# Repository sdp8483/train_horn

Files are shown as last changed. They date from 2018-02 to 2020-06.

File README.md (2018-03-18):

# Train Horn Synthesis with the MSP430FR2000
This readme is a short version of the blog post avalible on my personal website. Please read the blog post if you need more information: [link to blog]

## Introduction
The hardware and code presented is designed to simulate the sound of a train horn (or come as close as possible with the given hardware). Specifically is is designed to synthesize the sound of a [Leslie S-3L Locomotive Air Horn](http://www.dieselairhorns.com/sounds/LeslieS3L.mp3).

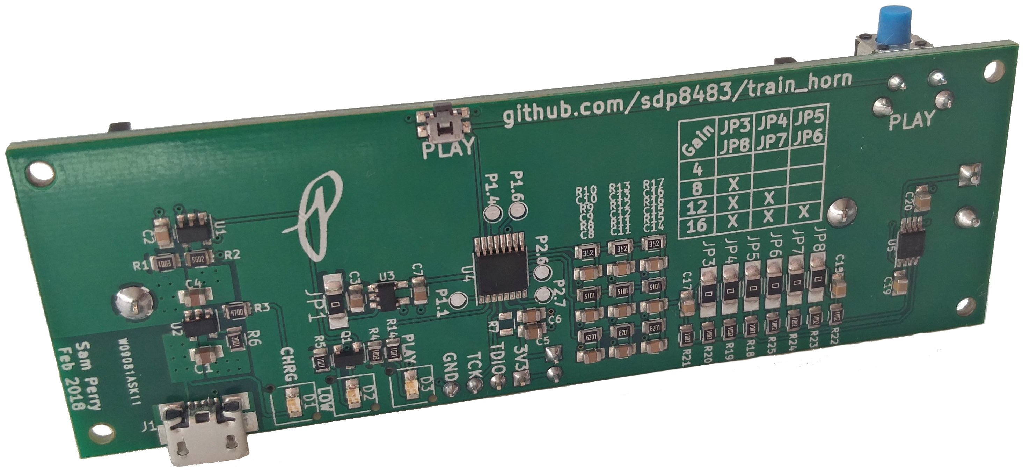
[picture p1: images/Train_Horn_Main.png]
Train Horn Assembly


The final design is battery powered for portability. It uses a 18650 LiPo cell and features an onboard charger using a standard micro USB port and a low battery indicator LED.

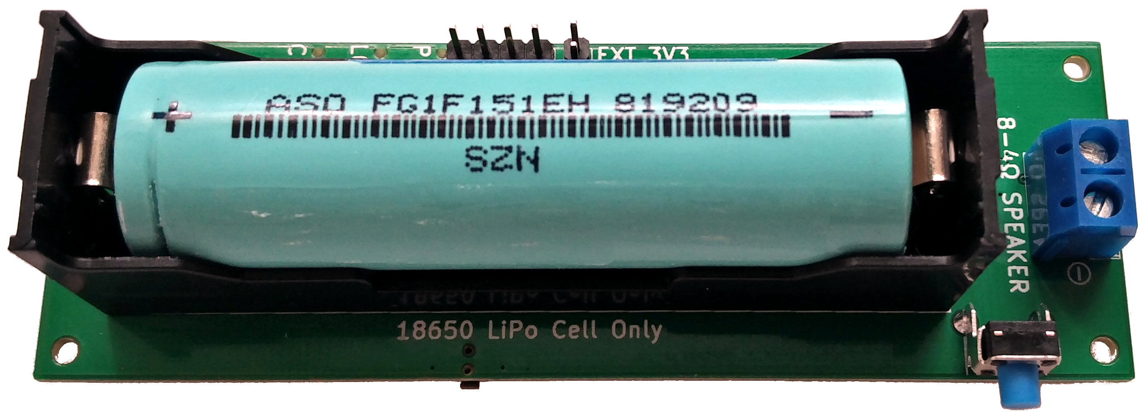
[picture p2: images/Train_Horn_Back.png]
Train Horn Assembly Back


The circuitry is able to drive a standard speaker load of 8-4Ω for mono sound. Four adjustable gain settings of 4, 8, 12, and 16 are available for setting the output volume of the audio amplifier with minimal modifications.

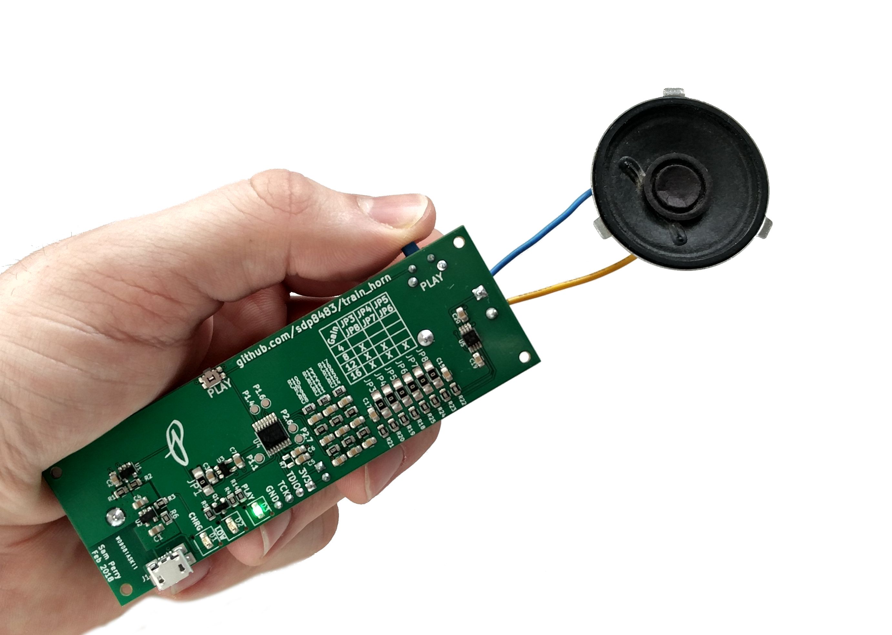
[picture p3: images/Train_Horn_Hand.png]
Train Horn in Hand


An onboard microcontroller generates the chord and enables the user control of the sound though a simple push button. The [MSP430FR2000](http://www.ti.com/product/MSP430FR2000) was chosen due to its low cost in single quantities and availability at the time of designing this product. The MSP430 line was chosen specifically to develop a familiarity with using the product.

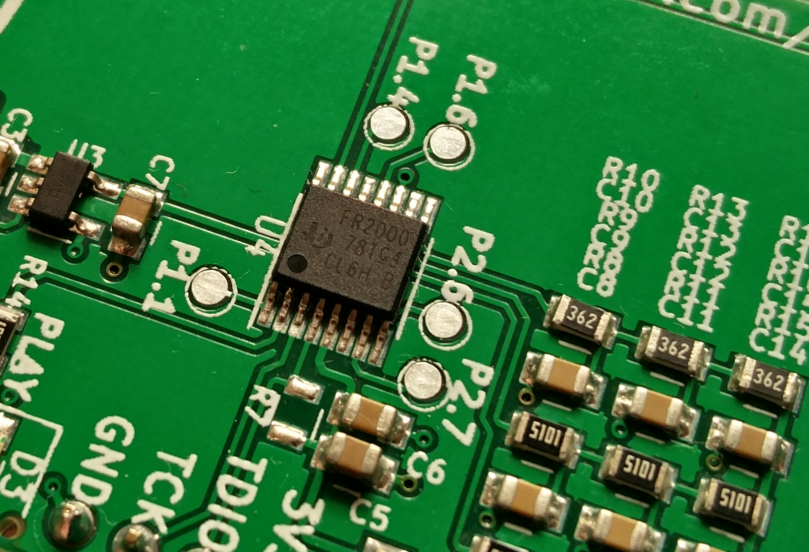
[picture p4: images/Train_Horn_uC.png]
MSP430FR2000 on PCB


## A Brief Overview

PCB Front Annotation
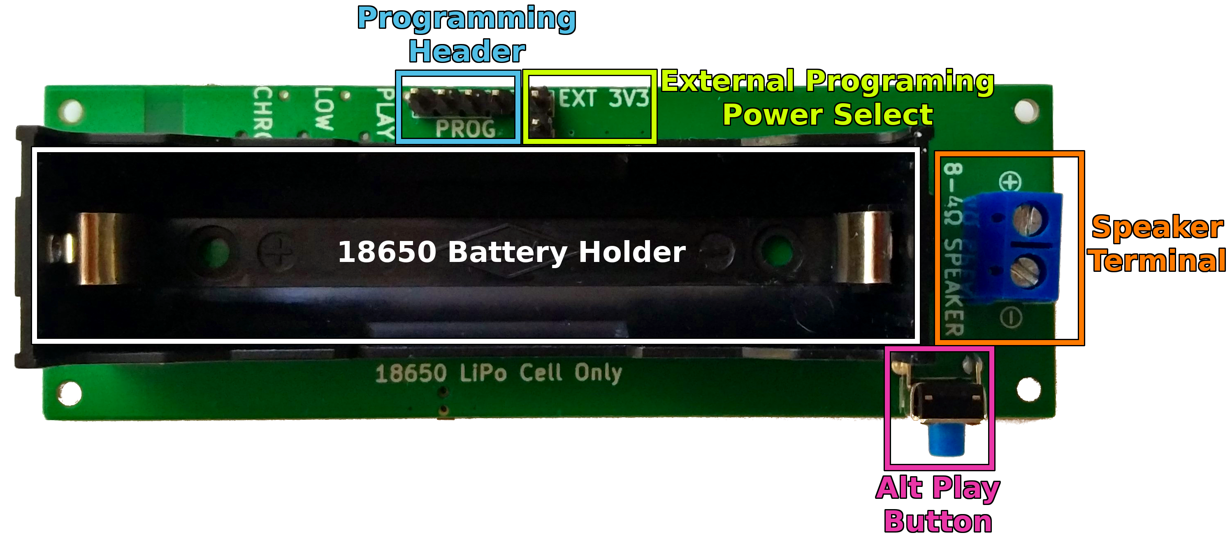
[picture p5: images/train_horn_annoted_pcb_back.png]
PCB Back Annotation


A 4-8Ω speaker is connected to the speaker terminal. The device is powered from a 18650 LiPo cell which is charged using the micro USB port, a blue LED indicates that the battery is charging. The charging circuitry is capable of charging the battery at a maximum current of 500mA.  The low battery detection circuitry will illuminate a red LED indicator light when the battery voltage is low and requires charging. The audio amplifier gain (volume) is configured using jumpers JP3-JP8 and is set to 16 by default. Pressing and holding either the small SMD or the larger right angle play button generates sound. A green LED is illuminated while sound is playing. Releasing the button stops sound generation.

## Schematic

Schematic

## Detailed Description
### Sound Generation
The Leslie S-3L Locomotive Air Horn generates its distinctive [sound](http://www.dieselairhorns.com/sounds/LeslieS3L.mp3) using a three tone chord of approximately C, D#, and A [http://atsf.railfan.net/airhorns/s3l.html](http://atsf.railfan.net/airhorns/s3l.html).

The onboard microcontroller generates the chord using three 50% duty cycle PWM signals. Since the MSP430FR2000 microcontroller has only one general purpose timer the method outlined in TI app note [SLAA513A](http://www.ti.com/lit/an/slaa513a/slaa513a.pdf) was implemented to generate multiple time bases on a single MSP430 timer module. This enables use of the lower cost MSP430FR2000 instead of having to move to a potentially higher cost MSP430 microcontroller with three separate timer modules.

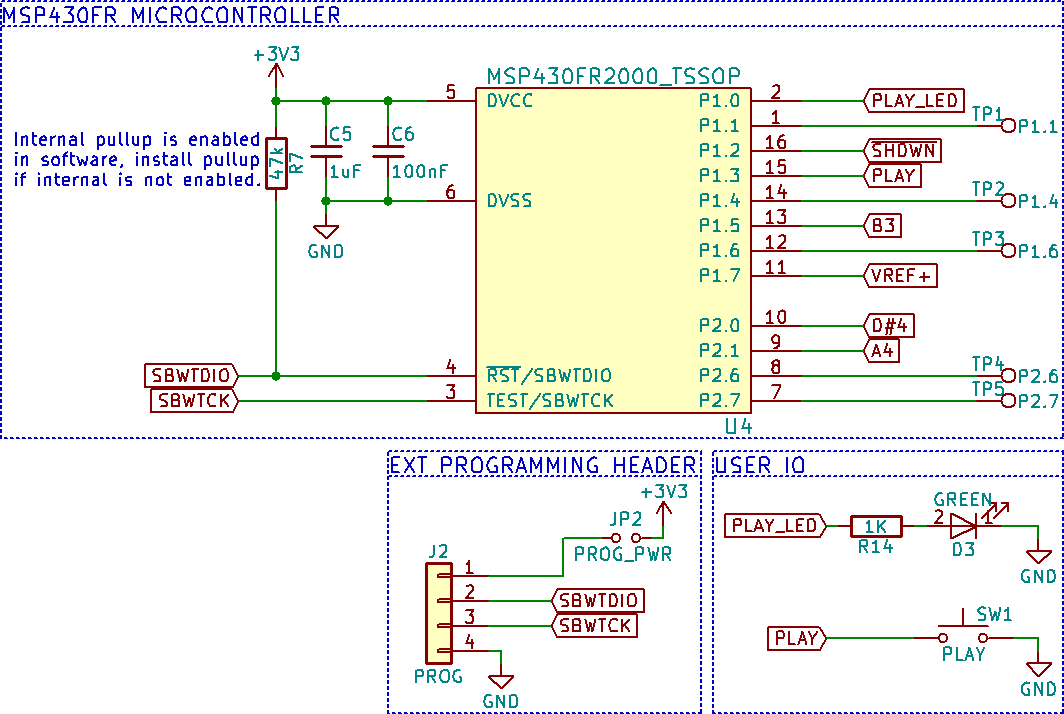
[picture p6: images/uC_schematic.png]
uC Schematic


Each PWM signal from the microcontroller is passed through a three stage RC low pass filter to produce a sine wave on the output.  The RC low pass filter was designed with the help of the following online RC low pass filter calculator: [http://sim.okawa-denshi.jp/en/CRtool.php](http://sim.okawa-denshi.jp/en/CRtool.php)

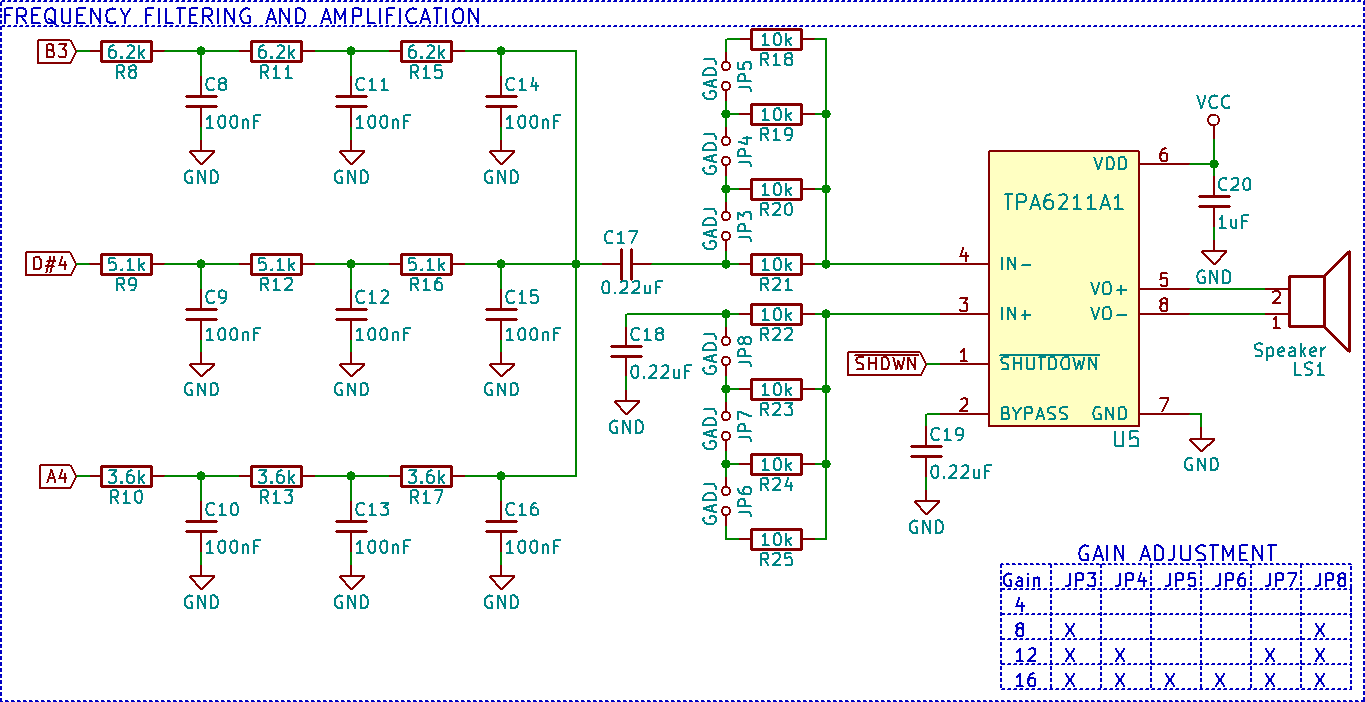
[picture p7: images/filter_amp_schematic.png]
Filter Amp Schematic


After each PWM signal is converted to a sine wave the signals are then mixed together before entering the audio amplifier. The audio amplifier is a [TPA6211A1](http://www.ti.com/lit/ds/symlink/tpa6211a1.pdf) mono audio power amplifier. The audio amplifier has 4 adjustable gain settings that can be changed by desoldering the smd jumpers (JP3 to JP6) as indicated by the table. For example to set a gain of eight JP4, JP5, JP6, and JP7 would be removed from the PCB. The amplifier can drive a 4-8Ω speaker.

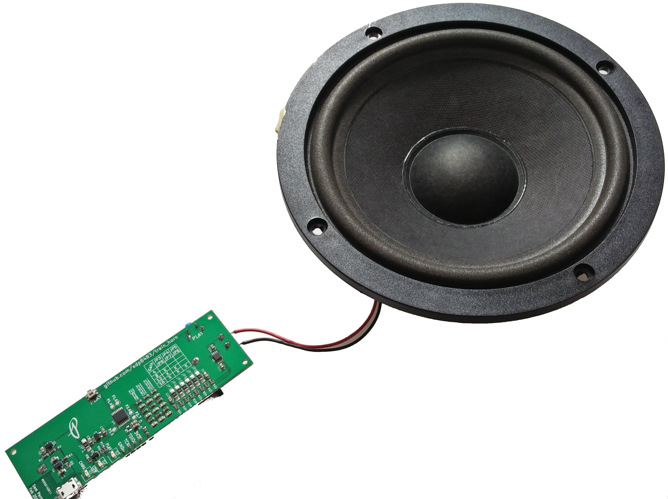
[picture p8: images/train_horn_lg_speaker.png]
Large Speaker


### Battery Circuitry
The circuit is powered with a standard 18650 LiPo cell. Be sure to observe polarity of the battery holder. The positive end of the battery installs opposite of the speaker terminal. Installing the battery in reverse polarity will destroy the battery charger IC and will damage the remaining circuitry. Don't ask me how I know.

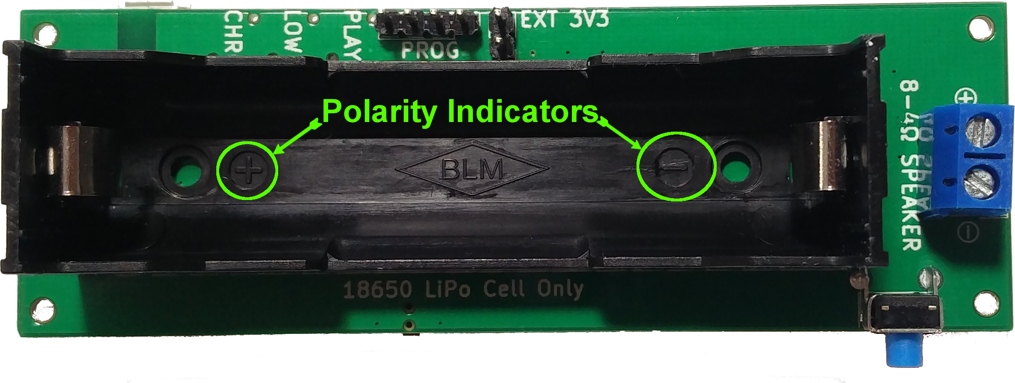
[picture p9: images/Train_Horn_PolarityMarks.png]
Observe Polarity!


Charging is controlled by the [MCP73831](https://www.microchip.com/wwwproducts/en/en024903) charge management IC at a maximum charging current of 500mA using the micro USB port. This USB port if for charging only, the data lines are not connected to the MSP430FR2000 microcontroller. A blue LED indicator is turned on while the battery charges. The LED turns off to indicate that the battery is fully charged.

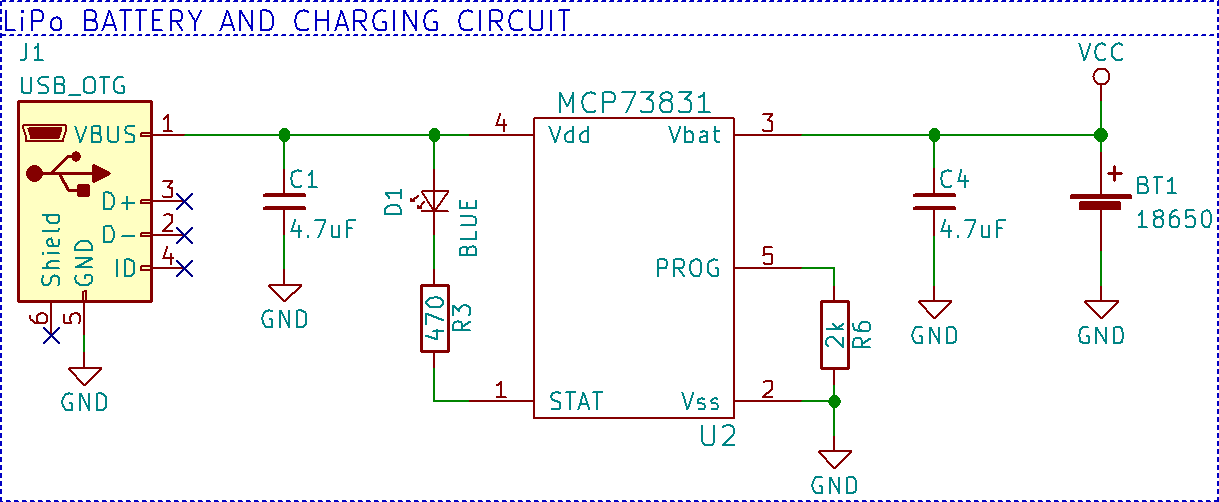
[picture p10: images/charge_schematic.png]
Battery Schematic

Battery Charging

A red LED is used to indicate a low battery voltage. The [MIC7221](http://ww1.microchip.com/downloads/en/DeviceDoc/mic7211.pdf) comparator is used to illuminate the LED when the battery voltage drops below ~3.3V. The internal 1.2V reference from the microcontroller is used as the voltage reference for the comparator.

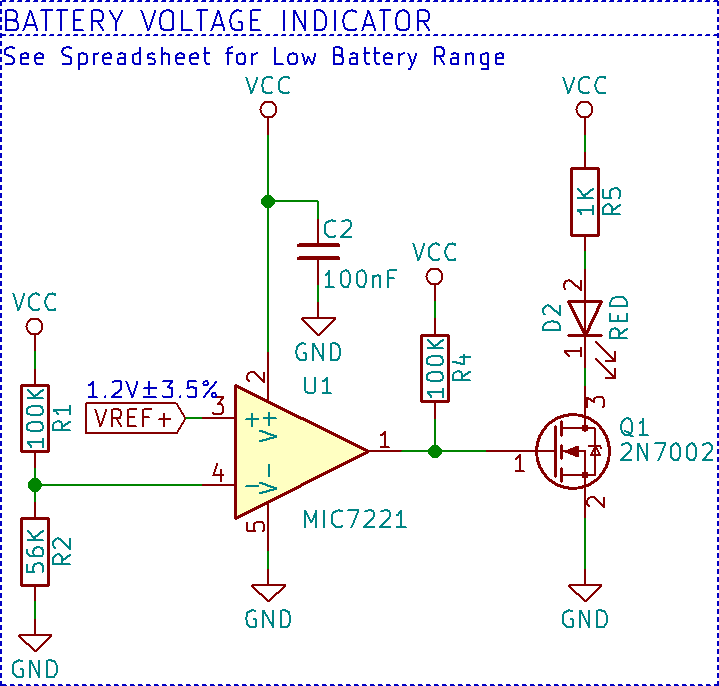
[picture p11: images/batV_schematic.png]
Low Battery Schematic


The onboard comparator of the MSP430FR2000 was not used due to issues with getting it to function correctly, most likely error on my part. To save time and frustration an external comparator was used instead.

Low Battery LED

The MSP430FR2000 microcontroller has a maximum voltage supply rating of 3.6V requiring a 3.3V low dropout regulator to prevent a fully charged LiPo cell voltage of 4.2V damaging the microcontroller. SMD JP1 can be desoldered from the circuit to put the LDO in shutdown mode, turning off the microcontroller.

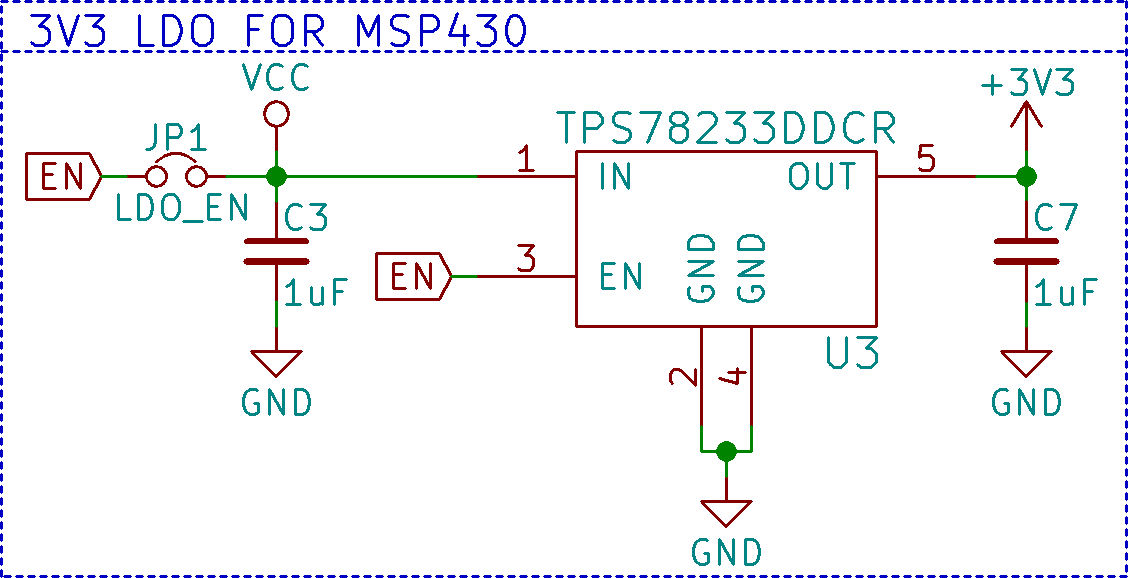
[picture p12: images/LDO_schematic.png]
LDO Schematic


### Firmware
The microcontroller spends much of its time in a low power sleep mode, the full circuit draws about 0.3mA of quiescent current. A 1600mAh LiPo cell will have a standby life of over [3700 hours](https://www.digikey.com/en/resources/conversion-calculators/conversion-calculator-battery-life) or 154 days!

Sound is generated when the user presses and holds down the play button. There are two play buttons on the PCB, a small SMD button and a friendlier medium sized right angle button. The PCB was originally designed to use only the SMD button but a last minute change added the right angle through hole button. Both are populated to allow multiple options of triggering sound generation. The green LED indicator is used to indicate when the sound is being generated.

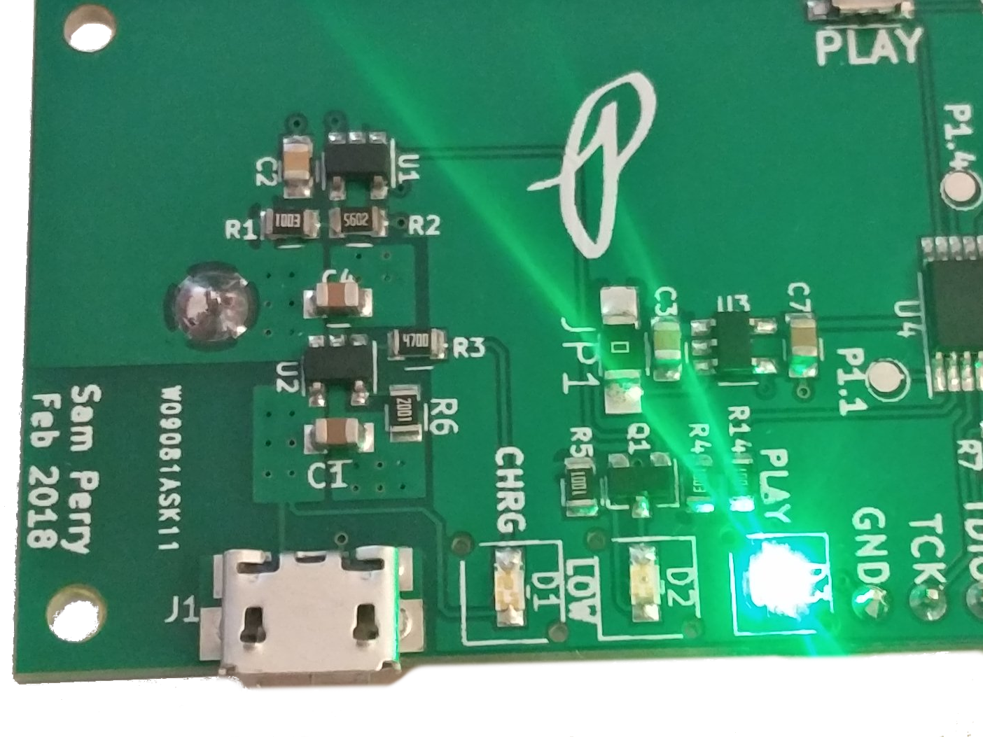
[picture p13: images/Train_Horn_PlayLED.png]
Play LED


Firmware is avalible here: [firmware/train_horn_hold/train_horn_hold.c](firmware/train_horn_hold/train_horn_hold.c)

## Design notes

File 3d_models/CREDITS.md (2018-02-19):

## Footprint Library Credits

The credits of 3D models are listed in respective folder.  
Please fill all 3D models credits and info source data accordingly.  

### Info requirements:
- Author
- if the 3D model is script generated, a link to the script generator is required as well as the version and sw used
- if the 3D model is manually generated, include the source model @ https://github.com/KiCad/packages3D-source

<hr>  

### Resistors_SMD.3dshapes:  
main author: Frank Shackmeister & Maurice easyw (others in script files) 
3D step & wrl parametric models generated by scripts (step in scale 1:1 mm, wrl derived from step and scaled 1/2.54)  
[FCAD_script_generator](https://github.com/easyw/kicad-3d-models-in-freecad/tree/master/cadquery/FCAD_script_generator)  
release version of sw used to create models:  
- FreeCAD 0.17  
- CadQuery 1.0.1  

R_01005_0402Metric
R_0201_0603Metric
R_0402_1005Metric
R_0603_1608Metric
R_0612_1632Metric
R_0805_2012Metric
R_0815_2038Metric
R_1020_2550Metric
R_1206_3216Metric
R_1210_3225Metric
R_1218_3246Metric
R_1806_4516Metric
R_1812_4532Metric
R_2010_5025Metric
R_2512_6332Metric
R_2816_7142Metric
R_4020_10251Metric

main author: Frank Shackmeister (others in script files)   
3D step & wrl parametric models generated by scripts (step in scale 1:1 mm, wrl derived from step and scaled 1/2.54)  
[FCAD_script_generator](https://github.com/easyw/kicad-3d-models-in-freecad/tree/master/cadquery/FCAD_script_generator)  
release version of sw used to create models:  
- FreeCAD 0.15 or FreeCAD 0.17 release >= 10647 
- CadQuery 0.5.2 or 1.0.1  

R_Array_Concave_2x0603  
R_Array_Concave_4x0402  
R_Array_Concave_4x0603  
R_Array_Convex_2x0402  
R_Array_Convex_2x0603  
R_Array_Convex_2x1206  
R_Array_Convex_4x0402  
R_Array_Convex_4x0603  
R_Array_Convex_4x1206  
R_Array_Convex_5x0603  
R_Array_Convex_5x1206  
R_Array_Convex_8x0602  
R_Cat16-2  
R_Cat16-4  
R_Cat16-8  

### Package_SO.3dshapes
main author: Maurice easyw (others in script files)
3D step & wrl parametric models generated by scripts (step in scale 1:1 mm, wrl derived from step and scaled 1/2.54)  
[FCAD_script_generator](https://github.com/easyw/kicad-3d-models-in-freecad/tree/master/cadquery/FCAD_script_generator)  
release version of sw used to create models:  
- FreeCAD 0.15 or FreeCAD 0.17 >= 10647  
- CadQuery 0.5.2  

SOIC-14_3.9x8.7mm_Pitch1.27mm  
SOIC-16W_7.5x10.3mm_Pitch1.27mm  
SOIC-16_3.9x9.9mm_Pitch1.27mm  
SOIC-18W_7.5x11.6mm_Pitch1.27mm  
SOIC-20W_7.5x12.8mm_Pitch1.27mm  
SOIC-24W_7.5x15.4mm_Pitch1.27mm  
SOIC-28W_7.5x17.9mm_Pitch1.27mm  
SOIC-8-1EP_3.9x4.9mm_Pitch1.27mm  
SOIC-8_3.9x4.9mm_Pitch1.27mm  
SOIJ-8_5.3x5.3mm_Pitch1.27mm  
MSOP-8-1EP_3x3mm_P0.65mm  
SSOP-20_5.3x7.2mm_P0.65mm  
TSSOP-14_4.4x5mm_P0.65mm  
QSOP-24_3.9x8.7mm_P0.635mm (https://github.com/easyw/kicad-3d-models-in-freecad/pull/31 joe-skb7)
ETSSOP-20-1EP_4.4x6.5mm_P0.65mm  
HTSSOP-20-1EP_4.4x6.5mm_P0.65mm_ThermalPad  
HTSSOP-28_4.4x9.7mm_P0.65mm_ThermalPad  
MSOP-10-1EP_3x3mm_P0.5mm  
MSOP-10_3x3mm_P0.5mm  
MSOP-12-16-1EP_3x4mm_P0.5mm  
MSOP-12-16_3x4mm_P0.5mm  
MSOP-12-1EP_3x4mm_P0.65mm  
MSOP-12_3x4mm_P0.65mm  
MSOP-16-1EP_3x4mm_P0.5mm  
MSOP-16_3x4mm_P0.5mm  
MSOP-8_3x3mm_P0.65mm  
OnSemi_Micro8  
PSOP-44_16.9x27.17mm_P1.27mm  
QSOP-16_3.9x4.9mm_P0.635mm  
SOP-16_4.4x10.4mm_P1.27mm  
SOP-4_4.4x2.8mm_P1.27mm  
SSOP-14_5.3x6.2mm_P0.65mm  
SSOP-16_3.9x4.9mm_P0.635mm  
SSOP-16_4.4x5.2mm_P0.65mm  
SSOP-16_5.3x6.2mm_P0.65mm  
SSOP-20_4.4x6.5mm_P0.65mm  
SSOP-24_3.9x8.7mm_P0.635mm  
SSOP-24_5.3x8.2mm_P0.65mm  
SSOP-28_5.3x10.2mm_P0.65mm  
SSOP-48_7.5x15.9mm_P0.635mm  
SSOP-56_7.5x18.5mm_P0.635mm  
SSOP-8_2.95x2.8mm_P0.65mm  
TSOP-I-48_12x18.4mm_P0.5mm  
TSOP-II-32_21.0x10.2mm_P1.27mm  
TSSOP-10_3x3mm_P0.5mm  
TSSOP-16-1EP_4.4x5mm_P0.65mm  
TSSOP-16_4.4x5mm_P0.65mm  
TSSOP-20_4.4x6.5mm_P0.65mm  
TSSOP-24_4.4x7.8mm_P0.65mm  
TSSOP-28_4.4x9.7mm_P0.65mm  
TSSOP-32_6.1x11mm_P0.65mm  
TSSOP-38_4.4x9.7mm_P0.5mm  
TSSOP-44_4.4x11.2mm_P0.5mm  
TSSOP-48_6.1x12.5mm_P0.5mm  
TSSOP-56_6.1x14mm_P0.5mm  
TSSOP-8_3x3mm_P0.65mm  
TSSOP-8_4.4x3mm_P0.65mm  
VSO-40_7.6x15.4mm_P0.762mm  
VSO-56_11.1x21.5mm_P0.75mm  
VSSOP-8_2.3x2mm_P0.5mm  
VSSOP-8_2.4x2.1mm_P0.5mm
SOP-4_3.8x4.1mm_P2.54mm

### Package_SO.3dshapes
main author: Stefan Olsson
3D step & wrl parametric models generated by scripts (step in scale 1:1 mm, wrl derived from step and scaled 1/2.54)  
[FCAD_script_generator](https://github.com/easyw/kicad-3d-models-in-freecad/tree/master/cadquery/FCAD_script_generator)  
release version of sw used to create models:  
- FreeCAD FreeCAD 0.17 Build 11223 64 bit Microsoft windwos platform https://www.freecadweb.org/

MFSOP6-4 (script)
MFSOP6-5 (script)
SO-20_12.8x7.5mm_Pitch1.27mm (modeled)

### Gull wing type packages  

main author: Frank Shackmeister and Maurice easyw (others in script files)
3D step & wrl parametric models generated by scripts (step in scale 1:1 mm, wrl derived from step and scaled 1/2.54)  
[FCAD_script_generator](https://github.com/easyw/kicad-3d-models-in-freecad/tree/master/cadquery/FCAD_script_generator)  
release version of sw used to create models:  
- FreeCAD 0.17  
- CadQuery 0.5.2  

Analog_KS-4  
SC-59  
SC-70-8  
SC-82AA  
SC-82AB  
SOT-143  
SOT-143R  
SOT-223  
SOT-23-5  
SOT-23-6  
SOT-23-8  
SOT-23  
SOT-323_SC-70  
SOT-343_SC-70-4  
SOT-353_SC-70-5  
SOT-363_SC-70-6  
SOT-383F  
SOT-383FL  
SOT-886
TSOT-23-5  
TSOT-23-6_MK06A  
TSOT-23-8  
TSOT-23
SOT-223-8
DRT-3
HVSOF5
HVSOF6
SOT-1333-1
SOT-1334-1
SOT-543
SOT-553
SOT-665
SOT-666
SOT-963
SuperSOT-3
SuperSOT-6
SuperSOT-8
TDSON-8-1
VSOF5

#### TO-220-7Lead_TabPin8

CadQuery script by hackscribble
[TO-220-7Lead_TabPin8](https://github.com/easyw/kicad-3d-models-in-freecad/pull/49)
FreeCAD 0.17 R10887
StepUp v5015
CadQuery 1.0.1

#### DPAK / D2PAK / D3PAK / ATPAK / HSOF8 / SOT669

CadQuery script by hackscribble
https://github.com/easyw/kicad-3d-models-in-freecad/pull/52
FreeCAD 0.17 R10958
StepUp v5015
CadQuery 1.0.0.1

TO-252-2 TO-252-3_TabPin2 TO-252-3_TabPin4
TO-252-4 TO-252-5_TabPin3 TO-252-5_TabPin6
TO-263-2 TO-263-3_TabPin2 TO-263-3_TabPin4
TO-263-4 TO-263-5_TabPin3 TO-263-5_TabPin6
TO-263-6 TO-263-7_TabPin4 TO-263-7_TabPin8
TO-268-2
ATPAK-2
Infineon_PG-HSOF-8-1
SOT-669_LFPAK
SOT-89-3

#### TO-277A, TO-277B, WSON-8-1EP_3x3mm
Author strombom
Modeled in Solidworks 2017 sp1
Exported to wrl in FreeCAD 0.16

TO-277A
TO-277B
WSON-8-1EP_3x3mm_P0.5mm_EP1.6x2.0mm

### Capacitors_SMD.3dshapes:  
main author: Maurice easyw & Frank Shack (others in script files) 
3D step & wrl parametric models generated by scripts (step in scale 1:1 mm, wrl derived from step and scaled 1/2.54)  
[FCAD_script_generator](https://github.com/easyw/kicad-3d-models-in-freecad/tree/master/cadquery/FCAD_script_generator)  
release version of sw used to create models:  
- FreeCAD 0.17
- CadQuery 1.0.0

CP_Elec_10x10.5  
CP_Elec_10x10  
CP_Elec_10x7.7  
CP_Elec_3x5.3  
CP_Elec_4x4.5  
CP_Elec_4x5.3  
CP_Elec_4x5.7  
CP_Elec_4x5.8  
CP_Elec_5x4.5  
CP_Elec_5x5.3  
CP_Elec_5x5.7  
CP_Elec_5x5.8  
CP_Elec_6.3x4.5  
CP_Elec_6.3x5.3  
CP_Elec_6.3x5.7  
CP_Elec_6.3x5.8  
CP_Elec_6.3x7.7  
CP_Elec_8x10.5  
CP_Elec_8x10  
CP_Elec_8x5.4  
CP_Elec_8x6.5  
CP_Elec_8x6.7  
C_01005_0402Metric
C_0201_0603Metric
C_0402_1005Metric
C_0603_1608Metric
C_0805_2012Metric
C_1206_3216Metric
C_2220_5650Metric
C_2225_5664Metric 
C_2512_6332Metric 
C_2816_7142Metric 
C_3640_9110Metric 
C_1210_3225Metric
C_1806_4516Metric
C_1812_4532Metric
C_1825_4564Metric
C_2010_5025Metric

### Buttons_Switches_THT:  
main author: Frank/Shack & Maurice/EasyW (others in script files)

release version of sw used to create models:  
- FC0.17
- CQ 1.0.0.1

PinHeader_1x01_P2.54mm_Horizontal
PinHeader_1x01_P2.54mm_Vertical
PinHeader_1x02_P2.54mm_Horizontal
PinHeader_1x02_P2.54mm_Vertical_SMD_Pin1Left
PinHeader_1x02_P2.54mm_Vertical_SMD_Pin1Right
PinHeader_1x02_P2.54mm_Vertical
PinHeader_1x03_P2.54mm_Horizontal
PinHeader_1x03_P2.54mm_Vertical_SMD_Pin1Left
PinHeader_1x03_P2.54mm_Vertical_SMD_Pin1Right
PinHeader_1x03_P2.54mm_Vertical
PinHeader_1x04_P2.54mm_Horizontal
PinHeader_1x04_P2.54mm_Vertical_SMD_Pin1Left
PinHeader_1x04_P2.54mm_Vertical_SMD_Pin1Right
PinHeader_1x04_P2.54mm_Vertical
PinHeader_1x05_P2.54mm_Horizontal
PinHeader_1x05_P2.54mm_Vertical_SMD_Pin1Left
PinHeader_1x05_P2.54mm_Vertical_SMD_Pin1Right
PinHeader_1x05_P2.54mm_Vertical
PinHeader_1x06_P2.54mm_Horizontal
PinHeader_1x06_P2.54mm_Vertical_SMD_Pin1Left
PinHeader_1x06_P2.54mm_Vertical_SMD_Pin1Right
PinHeader_1x06_P2.54mm_Vertical
PinHeader_1x07_P2.54mm_Horizontal
PinHeader_1x07_P2.54mm_Vertical_SMD_Pin1Left
PinHeader_1x07_P2.54mm_Vertical_SMD_Pin1Right
PinHeader_1x07_P2.54mm_Vertical
PinHeader_1x08_P2.54mm_Horizontal
PinHeader_1x08_P2.54mm_Vertical_SMD_Pin1Left
PinHeader_1x08_P2.54mm_Vertical_SMD_Pin1Right
PinHeader_1x08_P2.54mm_Vertical
PinHeader_1x09_P2.54mm_Horizontal
PinHeader_1x09_P2.54mm_Vertical_SMD_Pin1Left
PinHeader_1x09_P2.54mm_Vertical_SMD_Pin1Right
PinHeader_1x09_P2.54mm_Vertical
PinHeader_1x10_P2.54mm_Horizontal
PinHeader_1x10_P2.54mm_Vertical_SMD_Pin1Left
PinHeader_1x10_P2.54mm_Vertical_SMD_Pin1Right
PinHeader_1x10_P2.54mm_Vertical
PinHeader_1x11_P2.54mm_Horizontal
PinHeader_1x11_P2.54mm_Vertical_SMD_Pin1Left
PinHeader_1x11_P2.54mm_Vertical_SMD_Pin1Right
PinHeader_1x11_P2.54mm_Vertical
PinHeader_1x12_P2.54mm_Horizontal
PinHeader_1x12_P2.54mm_Vertical_SMD_Pin1Left
PinHeader_1x12_P2.54mm_Vertical_SMD_Pin1Right
PinHeader_1x12_P2.54mm_Vertical
PinHeader_1x13_P2.54mm_Horizontal
PinHeader_1x13_P2.54mm_Vertical_SMD_Pin1Left
PinHeader_1x13_P2.54mm_Vertical_SMD_Pin1Right
PinHeader_1x13_P2.54mm_Vertical
PinHeader_1x14_P2.54mm_Horizontal
PinHeader_1x14_P2.54mm_Vertical_SMD_Pin1Left
PinHeader_1x14_P2.54mm_Vertical_SMD_Pin1Right
PinHeader_1x14_P2.54mm_Vertical
PinHeader_1x15_P2.54mm_Horizontal
PinHeader_1x15_P2.54mm_Vertical_SMD_Pin1Left
PinHeader_1x15_P2.54mm_Vertical_SMD_Pin1Right
PinHeader_1x15_P2.54mm_Vertical
PinHeader_1x16_P2.54mm_Horizontal
PinHeader_1x16_P2.54mm_Vertical_SMD_Pin1Left
PinHeader_1x16_P2.54mm_Vertical_SMD_Pin1Right
PinHeader_1x16_P2.54mm_Vertical
PinHeader_1x17_P2.54mm_Horizontal
PinHeader_1x17_P2.54mm_Vertical_SMD_Pin1Left
PinHeader_1x17_P2.54mm_Vertical_SMD_Pin1Right
PinHeader_1x17_P2.54mm_Vertical
PinHeader_1x18_P2.54mm_Horizontal
PinHeader_1x18_P2.54mm_Vertical_SMD_Pin1Left
PinHeader_1x18_P2.54mm_Vertical_SMD_Pin1Right
PinHeader_1x18_P2.54mm_Vertical
PinHeader_1x19_P2.54mm_Horizontal
PinHeader_1x19_P2.54mm_Vertical_SMD_Pin1Left
PinHeader_1x19_P2.54mm_Vertical_SMD_Pin1Right
PinHeader_1x19_P2.54mm_Vertical
PinHeader_1x20_P2.54mm_Horizontal
PinHeader_1x20_P2.54mm_Vertical_SMD_Pin1Left
PinHeader_1x20_P2.54mm_Vertical_SMD_Pin1Right
PinHeader_1x20_P2.54mm_Vertical
PinHeader_1x21_P2.54mm_Horizontal
PinHeader_1x21_P2.54mm_Vertical_SMD_Pin1Left
PinHeader_1x21_P2.54mm_Vertical_SMD_Pin1Right
PinHeader_1x21_P2.54mm_Vertical
PinHeader_1x22_P2.54mm_Horizontal
PinHeader_1x22_P2.54mm_Vertical_SMD_Pin1Left
PinHeader_1x22_P2.54mm_Vertical_SMD_Pin1Right
PinHeader_1x22_P2.54mm_Vertical
PinHeader_1x23_P2.54mm_Horizontal
PinHeader_1x23_P2.54mm_Vertical_SMD_Pin1Left
PinHeader_1x23_P2.54mm_Vertical_SMD_Pin1Right
PinHeader_1x23_P2.54mm_Vertical
PinHeader_1x24_P2.54mm_Horizontal
PinHeader_1x24_P2.54mm_Vertical_SMD_Pin1Left
PinHeader_1x24_P2.54mm_Vertical_SMD_Pin1Right
PinHeader_1x24_P2.54mm_Vertical
PinHeader_1x25_P2.54mm_Horizontal
PinHeader_1x25_P2.54mm_Vertical_SMD_Pin1Left
PinHeader_1x25_P2.54mm_Vertical_SMD_Pin1Right
PinHeader_1x25_P2.54mm_Vertical
PinHeader_1x26_P2.54mm_Horizontal
PinHeader_1x26_P2.54mm_Vertical_SMD_Pin1Left
PinHeader_1x26_P2.54mm_Vertical_SMD_Pin1Right
PinHeader_1x26_P2.54mm_Vertical
PinHeader_1x27_P2.54mm_Horizontal
PinHeader_1x27_P2.54mm_Vertical_SMD_Pin1Left
PinHeader_1x27_P2.54mm_Vertical_SMD_Pin1Right
PinHeader_1x27_P2.54mm_Vertical
PinHeader_1x28_P2.54mm_Horizontal
PinHeader_1x28_P2.54mm_Vertical_SMD_Pin1Left
PinHeader_1x28_P2.54mm_Vertical_SMD_Pin1Right
PinHeader_1x28_P2.54mm_Vertical
PinHeader_1x29_P2.54mm_Horizontal
PinHeader_1x29_P2.54mm_Vertical_SMD_Pin1Left
PinHeader_1x29_P2.54mm_Vertical_SMD_Pin1Right
PinHeader_1x29_P2.54mm_Vertical
PinHeader_1x30_P2.54mm_Horizontal
PinHeader_1x30_P2.54mm_Vertical_SMD_Pin1Left
PinHeader_1x30_P2.54mm_Vertical_SMD_Pin1Right
PinHeader_1x30_P2.54mm_Vertical
PinHeader_1x31_P2.54mm_Horizontal
PinHeader_1x31_P2.54mm_Vertical_SMD_Pin1Left
PinHeader_1x31_P2.54mm_Vertical_SMD_Pin1Right
PinHeader_1x31_P2.54mm_Vertical
PinHeader_1x32_P2.54mm_Horizontal
PinHeader_1x32_P2.54mm_Vertical_SMD_Pin1Left
PinHeader_1x32_P2.54mm_Vertical_SMD_Pin1Right
PinHeader_1x32_P2.54mm_Vertical
PinHeader_1x33_P2.54mm_Horizontal
PinHeader_1x33_P2.54mm_Vertical_SMD_Pin1Left
PinHeader_1x33_P2.54mm_Vertical_SMD_Pin1Right
PinHeader_1x33_P2.54mm_Vertical
PinHeader_1x34_P2.54mm_Horizontal
PinHeader_1x34_P2.54mm_Vertical_SMD_Pin1Left
PinHeader_1x34_P2.54mm_Vertical_SMD_Pin1Right
PinHeader_1x34_P2.54mm_Vertical
PinHeader_1x35_P2.54mm_Horizontal
PinHeader_1x35_P2.54mm_Vertical_SMD_Pin1Left
PinHeader_1x35_P2.54mm_Vertical_SMD_Pin1Right
PinHeader_1x35_P2.54mm_Vertical
PinHeader_1x36_P2.54mm_Horizontal
PinHeader_1x36_P2.54mm_Vertical_SMD_Pin1Left
PinHeader_1x36_P2.54mm_Vertical_SMD_Pin1Right
PinHeader_1x36_P2.54mm_Vertical
PinHeader_1x37_P2.54mm_Horizontal
PinHeader_1x37_P2.54mm_Vertical_SMD_Pin1Left
PinHeader_1x37_P2.54mm_Vertical_SMD_Pin1Right
PinHeader_1x37_P2.54mm_Vertical
PinHeader_1x38_P2.54mm_Horizontal
PinHeader_1x38_P2.54mm_Vertical_SMD_Pin1Left
PinHeader_1x38_P2.54mm_Vertical_SMD_Pin1Right
PinHeader_1x38_P2.54mm_Vertical
PinHeader_1x39_P2.54mm_Horizontal
PinHeader_1x39_P2.54mm_Vertical_SMD_Pin1Left
PinHeader_1x39_P2.54mm_Vertical_SMD_Pin1Right
PinHeader_1x39_P2.54mm_Vertical
PinHeader_1x40_P2.54mm_Horizontal
PinHeader_1x40_P2.54mm_Vertical_SMD_Pin1Left
PinHeader_1x40_P2.54mm_Vertical_SMD_Pin1Right
PinHeader_1x40_P2.54mm_Vertical
PinHeader_2x01_P2.54mm_Horizontal
PinHeader_2x01_P2.54mm_Vertical_SMD
PinHeader_2x01_P2.54mm_Vertical
PinHeader_2x02_P2.54mm_Horizontal
PinHeader_2x02_P2.54mm_Vertical_SMD
PinHeader_2x02_P2.54mm_Vertical
PinHeader_2x03_P2.54mm_Horizontal
PinHeader_2x03_P2.54mm_Vertical_SMD
PinHeader_2x03_P2.54mm_Vertical
PinHeader_2x04_P2.54mm_Horizontal
PinHeader_2x04_P2.54mm_Vertical_SMD
PinHeader_2x04_P2.54mm_Vertical
PinHeader_2x05_P2.54mm_Horizontal
PinHeader_2x05_P2.54mm_Vertical_SMD
PinHeader_2x05_P2.54mm_Vertical
PinHeader_2x06_P2.54mm_Horizontal
PinHeader_2x06_P2.54mm_Vertical_SMD
PinHeader_2x06_P2.54mm_Vertical
PinHeader_2x07_P2.54mm_Horizontal
PinHeader_2x07_P2.54mm_Vertical_SMD
PinHeader_2x07_P2.54mm_Vertical
PinHeader_2x08_P2.54mm_Horizontal
PinHeader_2x08_P2.54mm_Vertical_SMD
PinHeader_2x08_P2.54mm_Vertical
PinHeader_2x09_P2.54mm_Horizontal
PinHeader_2x09_P2.54mm_Vertical_SMD
PinHeader_2x09_P2.54mm_Vertical
PinHeader_2x10_P2.54mm_Horizontal
PinHeader_2x10_P2.54mm_Vertical_SMD
PinHeader_2x10_P2.54mm_Vertical
PinHeader_2x11_P2.54mm_Horizontal
PinHeader_2x11_P2.54mm_Vertical_SMD
PinHeader_2x11_P2.54mm_Vertical
PinHeader_2x12_P2.54mm_Horizontal
PinHeader_2x12_P2.54mm_Vertical_SMD
PinHeader_2x12_P2.54mm_Vertical
PinHeader_2x13_P2.54mm_Horizontal
PinHeader_2x13_P2.54mm_Vertical_SMD
PinHeader_2x13_P2.54mm_Vertical
PinHeader_2x14_P2.54mm_Horizontal
PinHeader_2x14_P2.54mm_Vertical_SMD
PinHeader_2x14_P2.54mm_Vertical
PinHeader_2x15_P2.54mm_Horizontal
PinHeader_2x15_P2.54mm_Vertical_SMD
PinHeader_2x15_P2.54mm_Vertical
PinHeader_2x16_P2.54mm_Horizontal
PinHeader_2x16_P2.54mm_Vertical_SMD
PinHeader_2x16_P2.54mm_Vertical
PinHeader_2x17_P2.54mm_Horizontal
PinHeader_2x17_P2.54mm_Vertical_SMD
PinHeader_2x17_P2.54mm_Vertical
PinHeader_2x18_P2.54mm_Horizontal
PinHeader_2x18_P2.54mm_Vertical_SMD
PinHeader_2x18_P2.54mm_Vertical
PinHeader_2x19_P2.54mm_Horizontal
PinHeader_2x19_P2.54mm_Vertical_SMD
PinHeader_2x19_P2.54mm_Vertical
PinHeader_2x20_P2.54mm_Horizontal
PinHeader_2x20_P2.54mm_Vertical_SMD
PinHeader_2x20_P2.54mm_Vertical
PinHeader_2x21_P2.54mm_Horizontal
PinHeader_2x21_P2.54mm_Vertical_SMD
PinHeader_2x21_P2.54mm_Vertical
PinHeader_2x22_P2.54mm_Horizontal
PinHeader_2x22_P2.54mm_Vertical_SMD
PinHeader_2x22_P2.54mm_Vertical
PinHeader_2x23_P2.54mm_Horizontal
PinHeader_2x23_P2.54mm_Vertical_SMD
PinHeader_2x23_P2.54mm_Vertical
PinHeader_2x24_P2.54mm_Horizontal
PinHeader_2x24_P2.54mm_Vertical_SMD
PinHeader_2x24_P2.54mm_Vertical
PinHeader_2x25_P2.54mm_Horizontal
PinHeader_2x25_P2.54mm_Vertical_SMD
PinHeader_2x25_P2.54mm_Vertical
PinHeader_2x26_P2.54mm_Horizontal
PinHeader_2x26_P2.54mm_Vertical_SMD
PinHeader_2x26_P2.54mm_Vertical
PinHeader_2x27_P2.54mm_Horizontal
PinHeader_2x27_P2.54mm_Vertical_SMD
PinHeader_2x27_P2.54mm_Vertical
PinHeader_2x28_P2.54mm_Horizontal
PinHeader_2x28_P2.54mm_Vertical_SMD
PinHeader_2x28_P2.54mm_Vertical
PinHeader_2x29_P2.54mm_Horizontal
PinHeader_2x29_P2.54mm_Vertical_SMD
PinHeader_2x29_P2.54mm_Vertical
PinHeader_2x30_P2.54mm_Horizontal
PinHeader_2x30_P2.54mm_Vertical_SMD
PinHeader_2x30_P2.54mm_Vertical
PinHeader_2x31_P2.54mm_Horizontal
PinHeader_2x31_P2.54mm_Vertical_SMD
PinHeader_2x31_P2.54mm_Vertical
PinHeader_2x32_P2.54mm_Horizontal
PinHeader_2x32_P2.54mm_Vertical_SMD
PinHeader_2x32_P2.54mm_Vertical
PinHeader_2x33_P2.54mm_Horizontal
PinHeader_2x33_P2.54mm_Vertical_SMD
PinHeader_2x33_P2.54mm_Vertical
PinHeader_2x34_P2.54mm_Horizontal
PinHeader_2x34_P2.54mm_Vertical_SMD
PinHeader_2x34_P2.54mm_Vertical
PinHeader_2x35_P2.54mm_Horizontal
PinHeader_2x35_P2.54mm_Vertical_SMD
PinHeader_2x35_P2.54mm_Vertical
PinHeader_2x36_P2.54mm_Horizontal
PinHeader_2x36_P2.54mm_Vertical_SMD
PinHeader_2x36_P2.54mm_Vertical
PinHeader_2x37_P2.54mm_Horizontal
PinHeader_2x37_P2.54mm_Vertical_SMD
PinHeader_2x37_P2.54mm_Vertical
PinHeader_2x38_P2.54mm_Horizontal
PinHeader_2x38_P2.54mm_Vertical_SMD
PinHeader_2x38_P2.54mm_Vertical
PinHeader_2x39_P2.54mm_Horizontal
PinHeader_2x39_P2.54mm_Vertical_SMD
PinHeader_2x39_P2.54mm_Vertical
PinHeader_2x40_P2.54mm_Horizontal
PinHeader_2x40_P2.54mm_Vertical_SMD
PinHeader_2x40_P2.54mm_Vertical

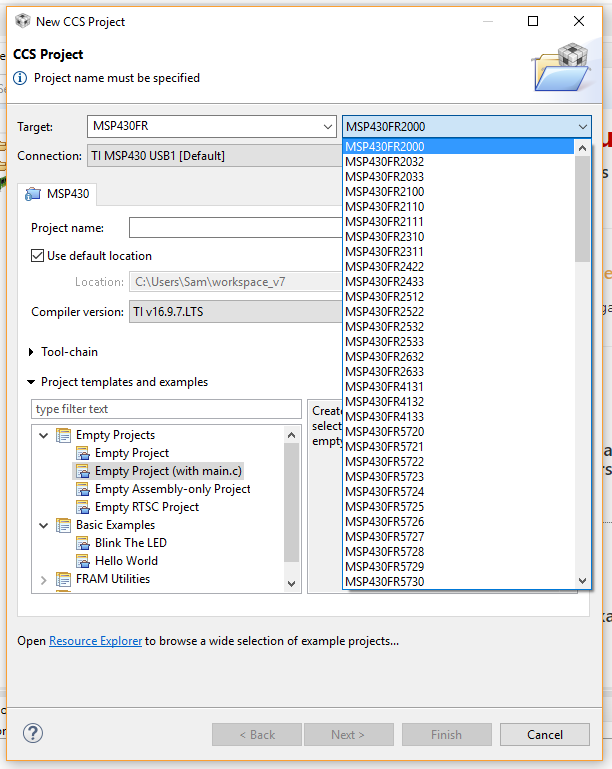
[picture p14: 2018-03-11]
images/NewCCSProject_Target.png

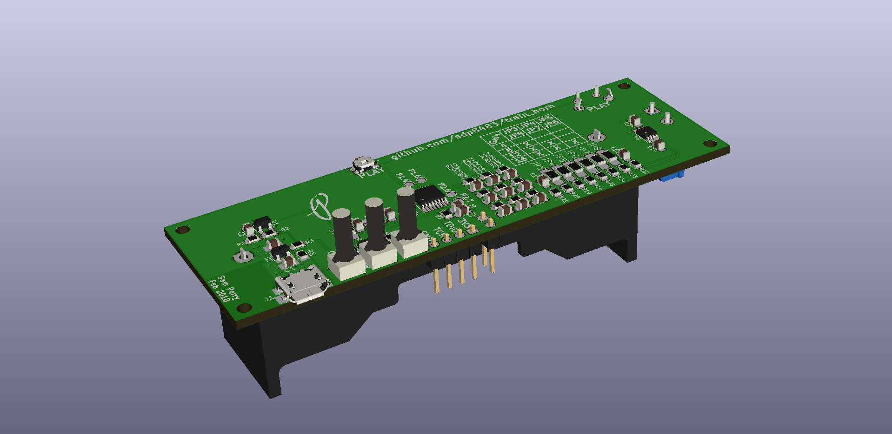
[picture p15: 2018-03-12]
images/train_horn_3dView.png

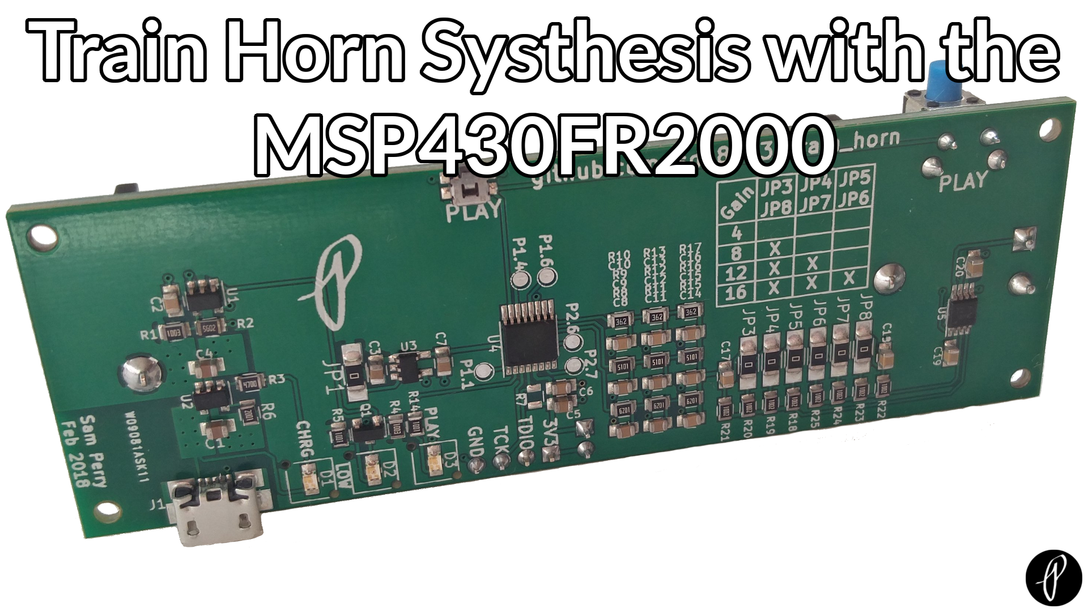
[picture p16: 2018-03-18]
images/Train_Horn_tumbnail.png

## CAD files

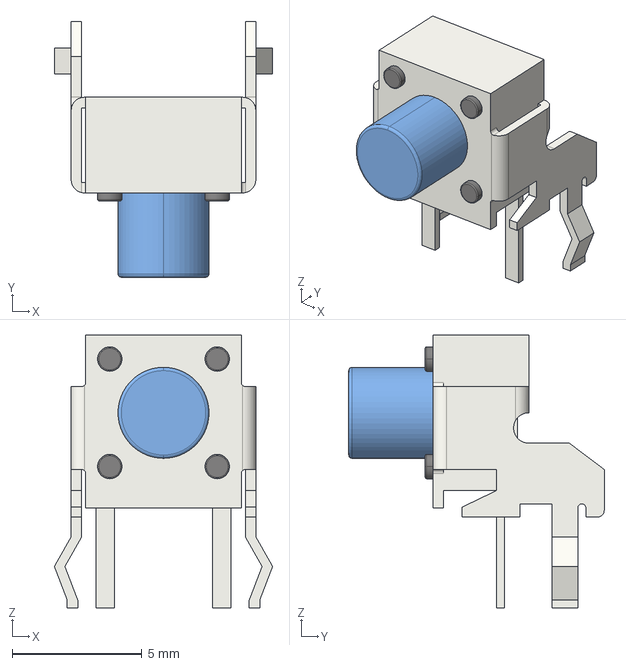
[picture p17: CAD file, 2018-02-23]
3d_models/C-1825027-8.step
8.41 x 9.84 x 10.5 mm

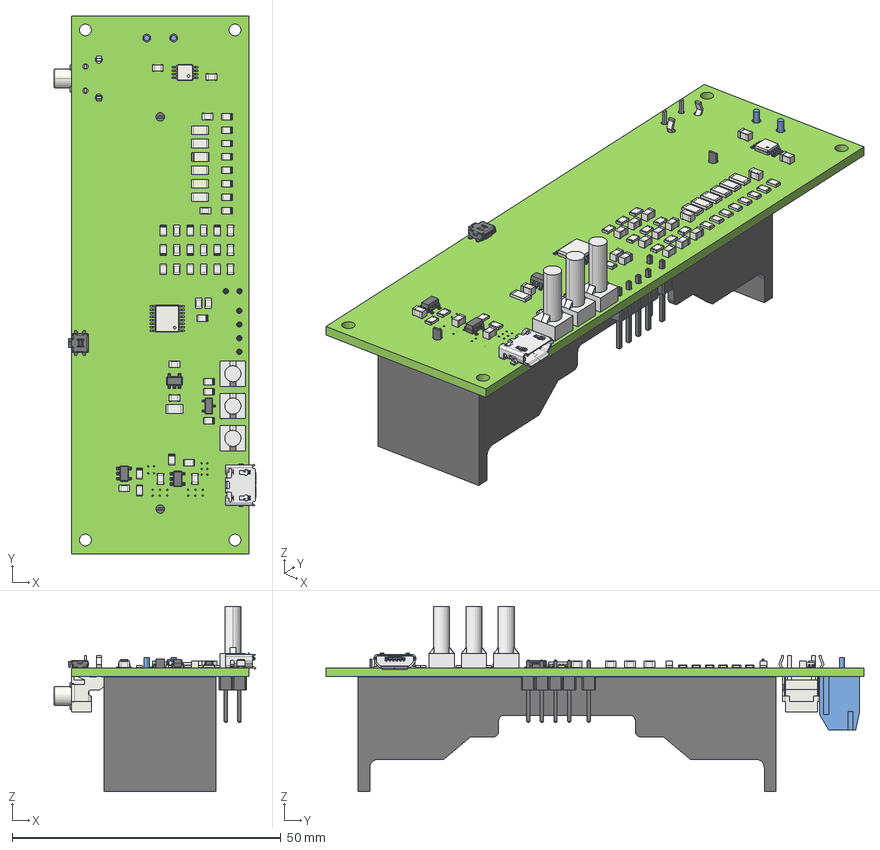
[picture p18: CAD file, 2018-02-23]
train_horn.FCStd
37.5 x 100.0 x 34.5 mm
Pcb
C-1825027-8_
C-1776244-2_
TSSOP_16_44x5mm_P065mm_
BH-18650-PC_
VLP_450_F042_
EVQP7L01P_
MSOP_8_1EP_3x3mm_P065mm_
USB_micro_Amphenol_10118820_
C_0805_2012Metric_
C_0805_2012Metric_001
C_0805_2012Metric_002
C_0805_2012Metric_003
C_0805_2012Metric_004
C_0805_2012Metric_005
C_0805_2012Metric_006
C_0805_2012Metric_007
C_0805_2012Metric_008
C_0805_2012Metric_009
C_0805_2012Metric_010
C_0805_2012Metric_011
C_0805_2012Metric_012
C_0805_2012Metric_013
C_0805_2012Metric_014
C_0805_2012Metric_015
C_0805_2012Metric_016
C_0805_2012Metric_017
C_0805_2012Metric_018
C_0805_2012Metric_019
PinHeader_1x04_P254mm_Vertical_
SOT_23_
R_0805_2012Metric_
R_0805_2012Metric_001
R_0805_2012Metric_002
R_0805_2012Metric_003
R_0805_2012Metric_004
R_0805_2012Metric_005
R_0805_2012Metric_006
R_0805_2012Metric_007
R_0805_2012Metric_008
R_0805_2012Metric_009
R_0805_2012Metric_010
R_0805_2012Metric_011
R_0805_2012Metric_012
R_0805_2012Metric_013
R_0805_2012Metric_014
R_0805_2012Metric_015
R_0805_2012Metric_016
R_0805_2012Metric_017
R_0805_2012Metric_018
R_0805_2012Metric_019
R_0805_2012Metric_020
R_0805_2012Metric_021
R_0805_2012Metric_022
R_0805_2012Metric_023
R_0805_2012Metric_024
SOT_23_5_
SOT_23_5_001
SOT_23_5_002
R_1206_3216Metric_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

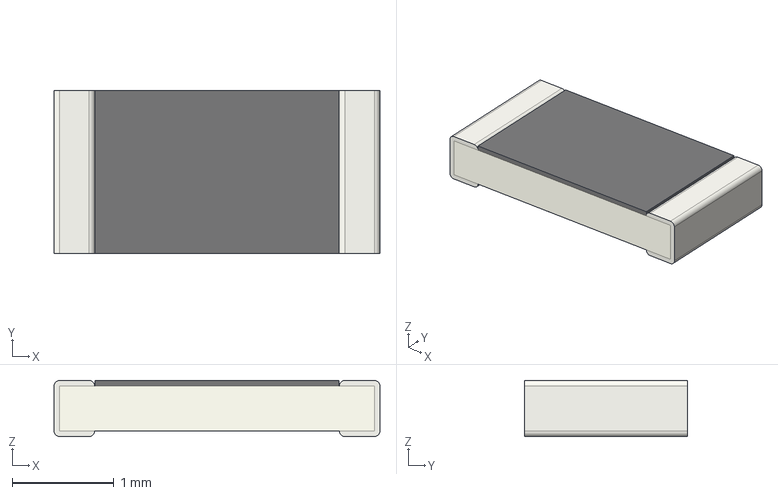
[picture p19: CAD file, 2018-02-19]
3d_models/R_1206_3216Metric.step
3.20 x 1.60 x 0.55 mm

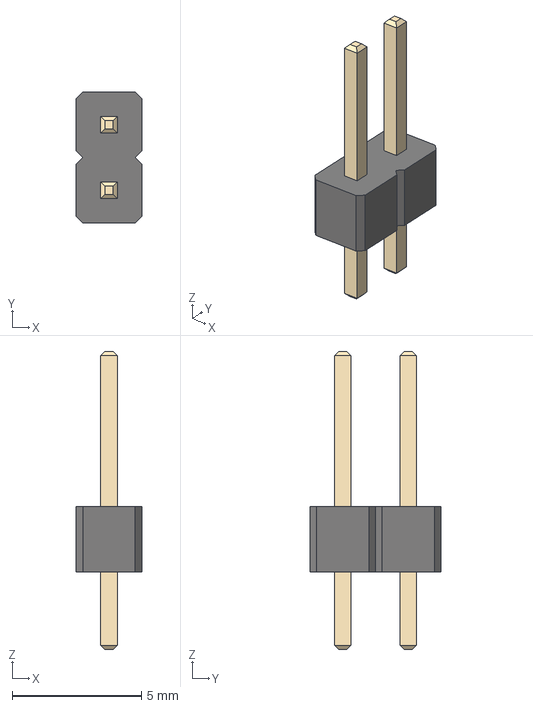
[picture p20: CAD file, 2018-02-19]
3d_models/PinHeader_1x02_P2.54mm_Vertical.step
2.54 x 5.08 x 11.5 mm

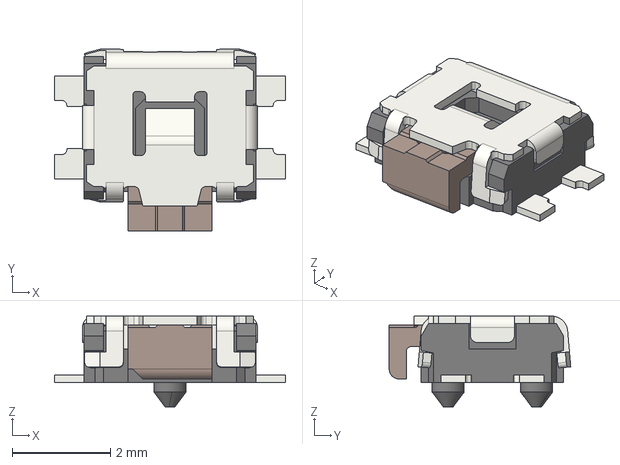
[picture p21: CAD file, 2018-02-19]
3d_models/EVQP7L01P.step
4.70 x 3.69 x 1.85 mm

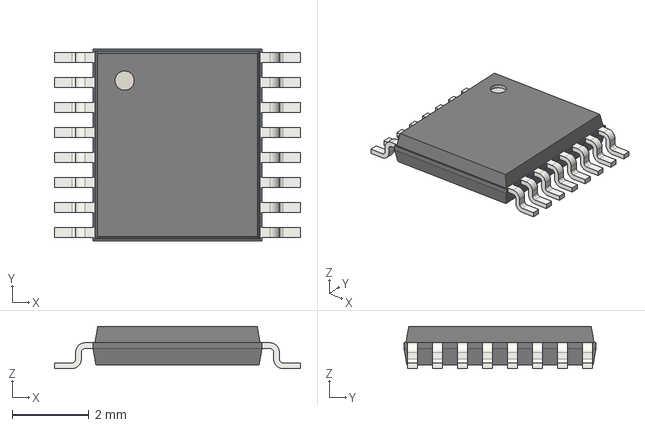
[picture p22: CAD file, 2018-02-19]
3d_models/TSSOP-16_4.4x5mm_P0.65mm.step
6.40 x 5.00 x 1.10 mm

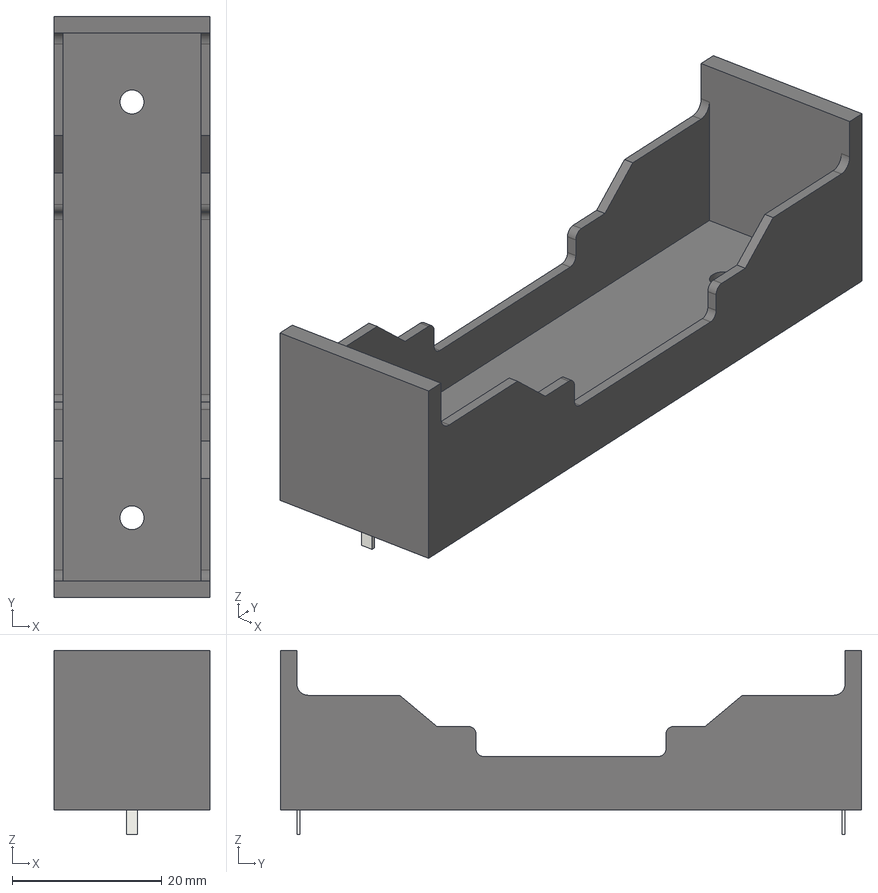
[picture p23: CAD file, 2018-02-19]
3d_models/BH-18650-PC.step
20.8 x 77.7 x 24.6 mm

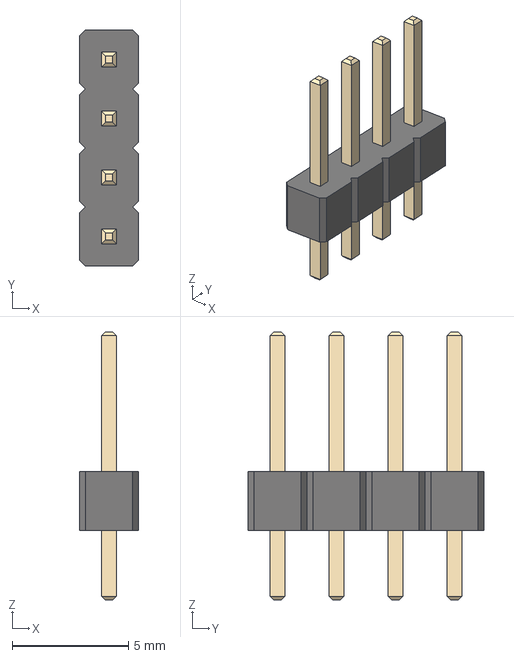
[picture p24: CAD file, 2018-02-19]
3d_models/PinHeader_1x04_P2.54mm_Vertical.step
2.54 x 10.2 x 11.5 mm

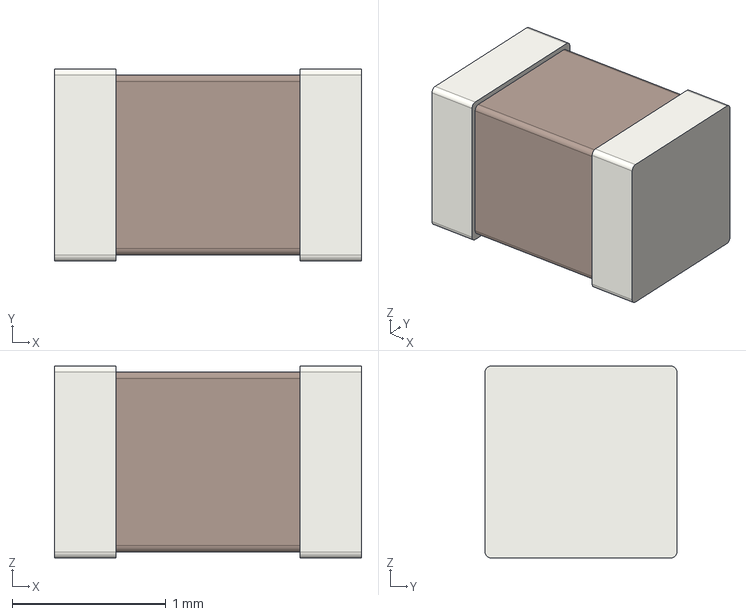
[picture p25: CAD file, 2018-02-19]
3d_models/C_0805_2012Metric.step
2.00 x 1.25 x 1.25 mm

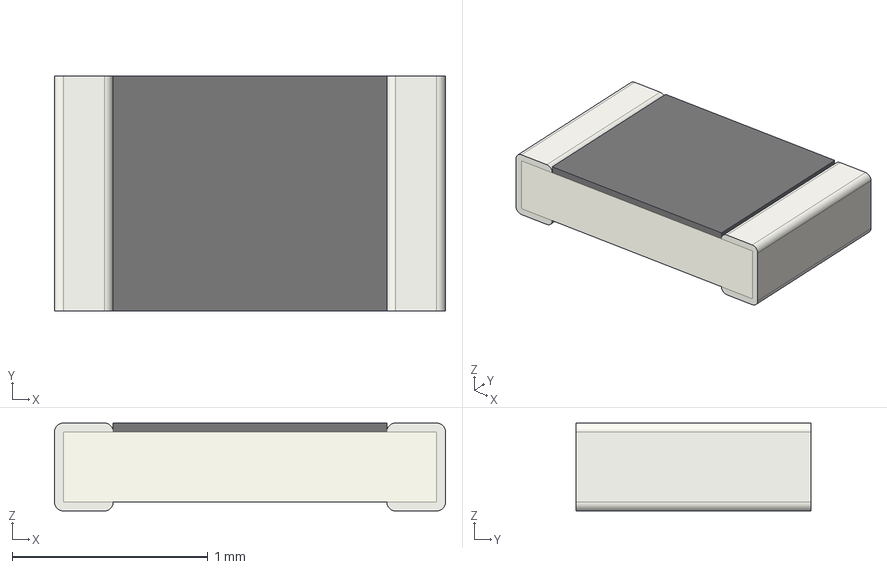
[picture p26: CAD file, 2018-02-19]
3d_models/R_0805_2012Metric.step
2.00 x 1.20 x 0.45 mm

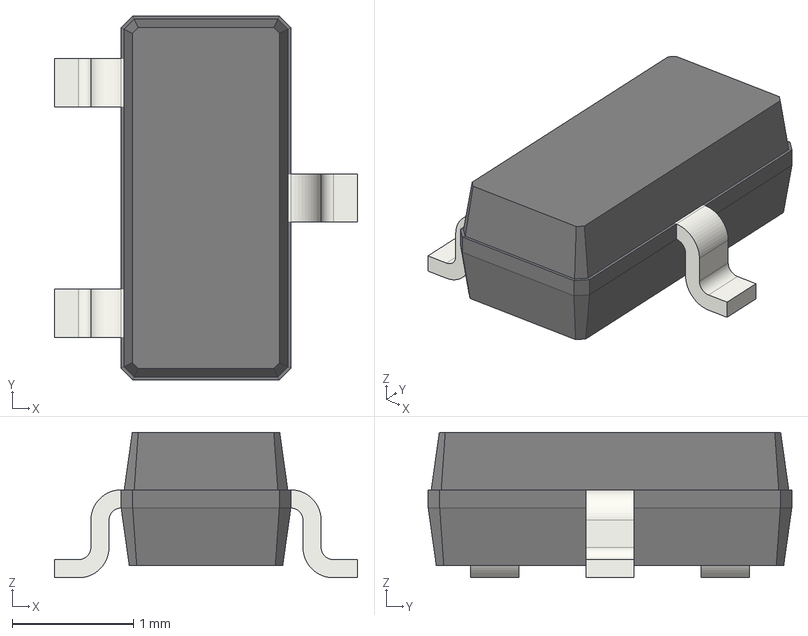
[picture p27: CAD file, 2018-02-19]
3d_models/SOT-23.step
2.50 x 3.00 x 1.20 mm

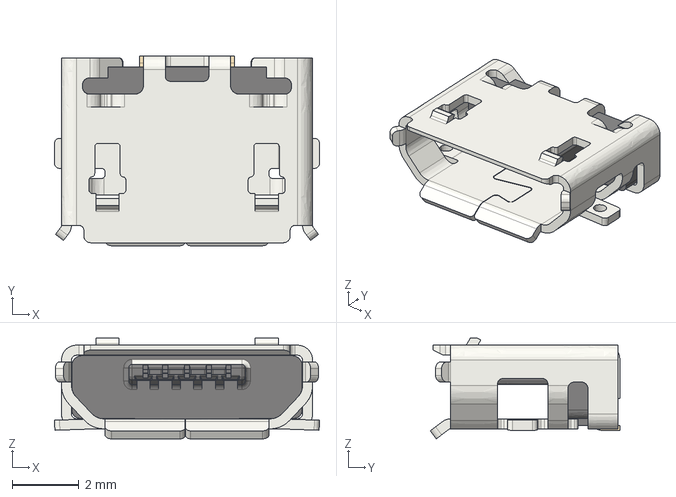
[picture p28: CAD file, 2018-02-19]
3d_models/USB_micro_Amphenol_10118192.step
7.91 x 5.66 x 3.01 mm

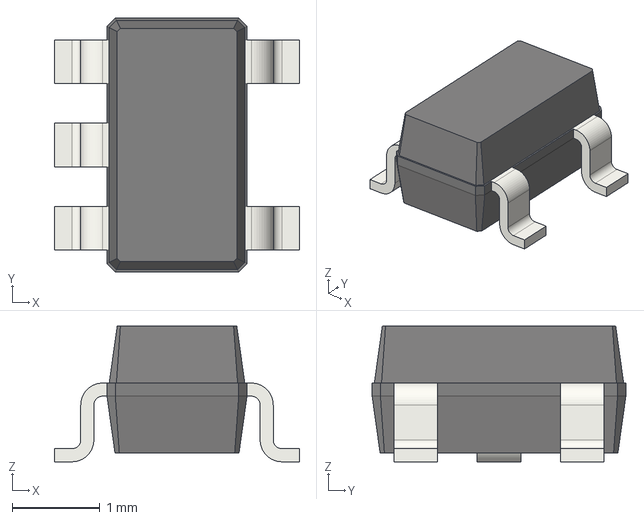
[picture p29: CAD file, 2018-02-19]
3d_models/SOT-23-5.step
2.80 x 2.90 x 1.55 mm

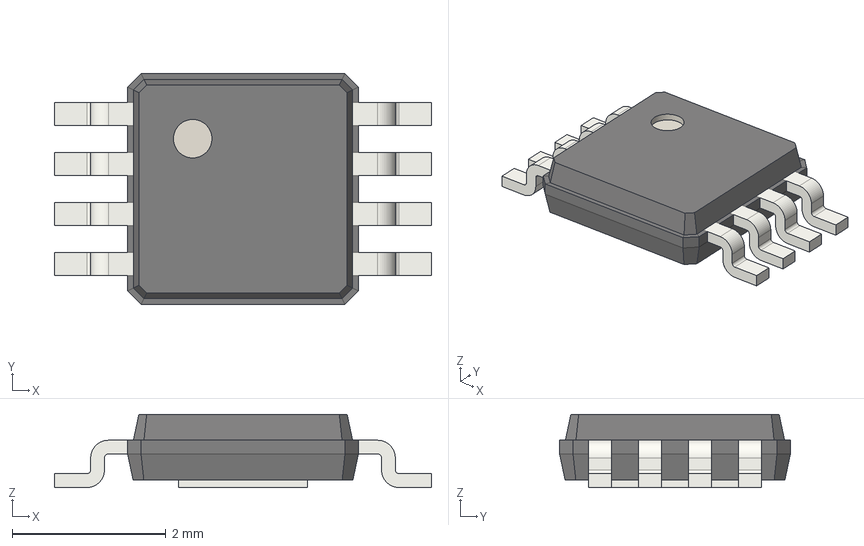
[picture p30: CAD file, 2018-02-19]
3d_models/MSOP-8-1EP_3x3mm_P0.65mm_EP1.68x1.88mm.step
4.90 x 3.00 x 0.95 mm

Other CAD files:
3d_models/Generic_5mm_2Pos_TerminalBlock.step
3d_models/VLP_450_F.step
3d_models/train_horn.FCStd

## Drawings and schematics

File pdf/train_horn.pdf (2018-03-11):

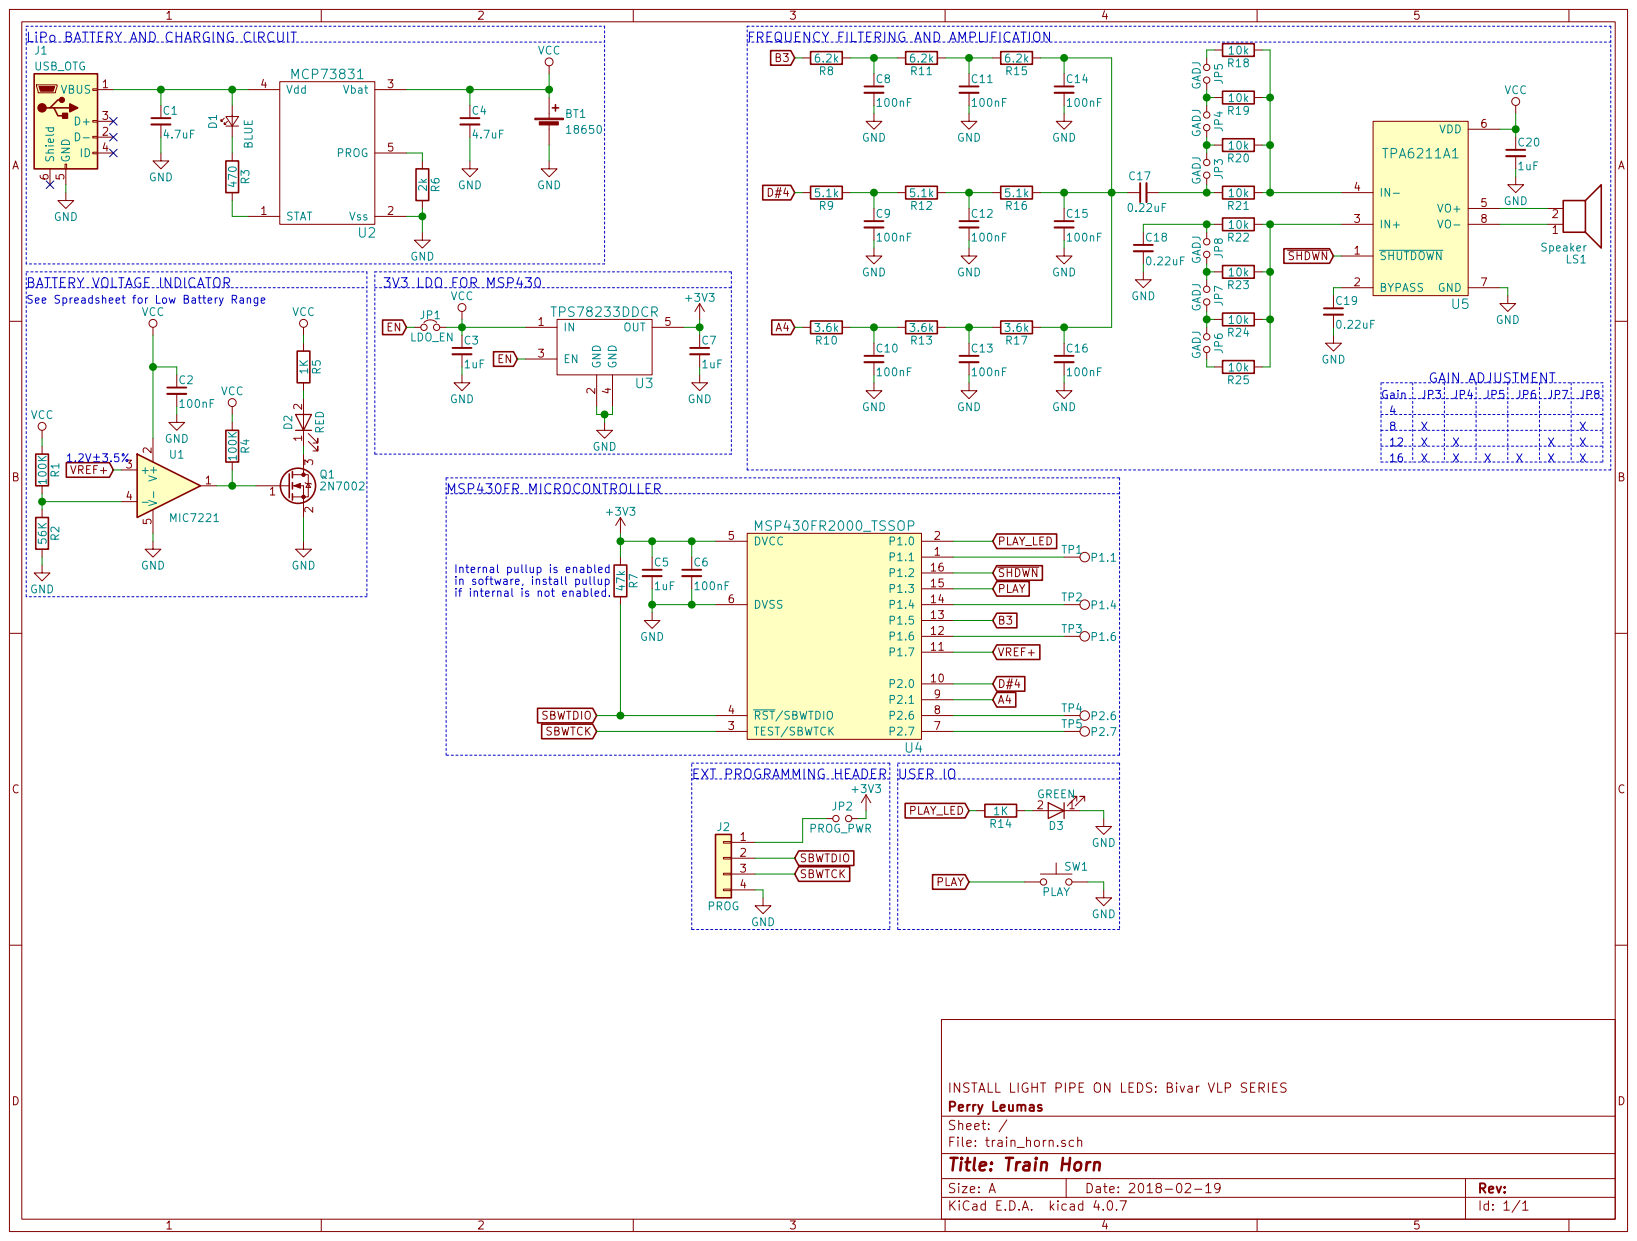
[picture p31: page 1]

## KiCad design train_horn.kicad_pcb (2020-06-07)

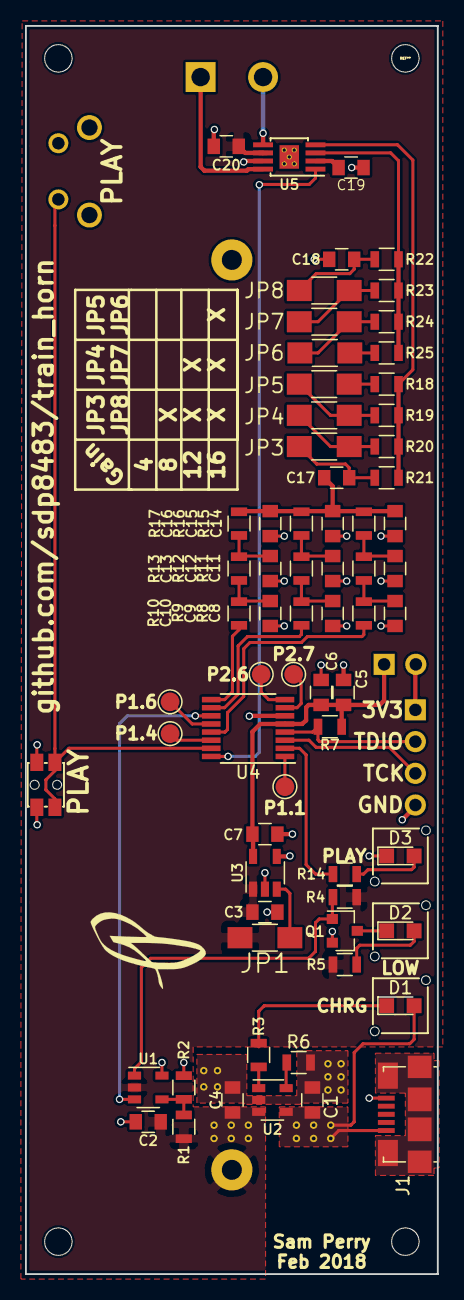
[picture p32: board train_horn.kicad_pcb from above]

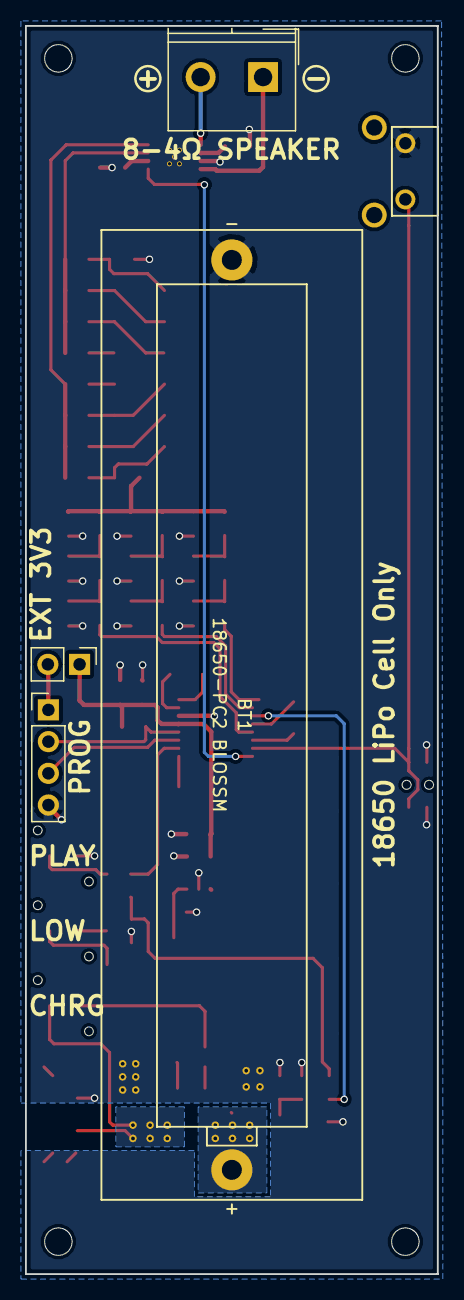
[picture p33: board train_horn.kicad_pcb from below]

Board: 2 copper layers, 33.0 x 100.0 mm, 72 parts (4 on the bottom side), 48 nets.

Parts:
BT1: 18650; 18650_battery_holder_PCB_Pins
C1, C4: 4.7uF; C_0805
C2, C6, C8, C9, C10, C11, C12, C13, C14, C15, C16: 100nF; C_0805
C3, C5, C7, C20: 1uF; C_0805
C17, C18, C19: 0.22uF; C_0805
D1: BLUE; LED_0805_LIGHTPIPE
D2: RED; LED_0805_LIGHTPIPE
D3: GREEN; LED_0805_LIGHTPIPE
J1: USB_OTG; USB_Micro-B_Amphenol_10118192-0001LF
J2: PROG; Pin_Header_Straight_1x04_Pitch2.54mm
JP1: LDO_EN; R_1206_HandSoldering
JP2: PROG_PWR; Pin_Header_Straight_1x02_Pitch2.54mm
JP3, JP4, JP5, JP6, JP7, JP8: GADJ; R_1206_HandSoldering
LS1: Speaker; TerminalBlock_02x5mm_Straight
Q1: 2N7002; SOT-23
R1, R4: 100K; R_0805
R2: 56K; R_0805
R3: 470; R_0805
R5: 1K; R_0805
R6: 2k; R_0805
R7: 47k; R_0805
R8, R11, R15: 6.2k; R_0805
R9, R12, R16: 5.1k; R_0805
R10, R13, R17: 3.6k; R_0805
R14: 1k; R_0805
R18, R19, R20, R21, R22, R23, R24, R25: 10k; R_0805
SW1: PLAY; SWITCH_Panasonic_SMDRight_EVQP7C
TP1: P1.1; Test_Point_Pad_d1.5mm
TP2: P1.4; Test_Point_Pad_d1.5mm
TP3: P1.6; Test_Point_Pad_d1.5mm
TP4: P2.6; Test_Point_Pad_d1.5mm
TP5: P2.7; Test_Point_Pad_d1.5mm
U1: MIC7221; SOT-23-5
U2: MCP73831; SOT-23-5
U3: TPS78233DDCR; TSOT-23-5
U4: MSP430FR2000_TSSOP; TSSOP-16_4.4x5mm_Pitch0.65mm
U5: TPA6211A1; TPA6211A1_MSOP

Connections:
+3V3: C5.1, C6.1, C7.1, JP2.1, R7.1, U3.5, U4.5
A4: R10.2, U4.9
B3: R8.2, U4.13
D#4: R9.2, U4.10
EN: JP1.1, U3.3
GND: BT1.2, C1.2, C2.2, C3.2, C4.2, C5.2, C6.2, C7.2, C8.2, C9.2, C10.2, C11.2, C12.2, C13.2, C14.2, C15.2, C16.2, C18.2, C19.2, C20.2, D3.1, J1.5, J2.4, Q1.2, R2.2, R6.2, SW1.2, U1.5, U2.2, U3.2, U3.4, U4.6, U5.7
unnamed: C1.1, D1.2, J1.1, U2.4
unnamed: C8.1, R8.1, R11.2
unnamed: C9.1, R9.1, R12.2
unnamed: C10.1, R10.1, R13.2
unnamed: C11.1, R11.1, R15.2
unnamed: C12.1, R12.1, R16.2
unnamed: C13.1, R13.1, R17.2
unnamed: C14.1, C15.1, C16.1, C17.1, R15.1, R16.1, R17.1
unnamed: C17.2, JP3.2, R21.2
unnamed: C18.1, JP8.1, R22.2
unnamed: C19.1, U5.2
unnamed: D1.1, R3.1
unnamed: D2.1, Q1.3
unnamed: D2.2, R5.2
unnamed: D3.2, R14.1
unnamed: J2.1, JP2.2
unnamed: JP3.1, JP4.2, R20.2
unnamed: JP4.1, JP5.2, R19.2
unnamed: JP5.1, R18.2
unnamed: JP6.1, JP7.2, R24.2
unnamed: JP6.2, R25.2
unnamed: JP7.1, JP8.2, R23.2
unnamed: LS1.1, U5.8
unnamed: LS1.2, U5.5
unnamed: Q1.1, R4.2, U1.1
unnamed: R1.2, R2.1, U1.4
unnamed: R3.2, U2.1
unnamed: R6.1, U2.5
unnamed: R18.1, R19.1, R20.1, R21.1, U5.4
unnamed: R22.1, R23.1, R24.1, R25.1, U5.3
unnamed: TP1.1, U4.1
unnamed: TP2.1, U4.14
unnamed: TP3.1, U4.12
unnamed: TP4.1, U4.8
unnamed: TP5.1, U4.7
PLAY: SW1.1, U4.15
PLAY_LED: R14.2, U4.2
SBWTCK: J2.3, U4.3
SBWTDIO: J2.2, R7.2, U4.4
VCC: BT1.1, C2.1, C3.1, C4.1, C20.1, JP1.2, R1.1, R4.1, R5.1, U1.2, U2.3, U3.1, U5.6
VREF+: U1.3, U4.11
~SHDWN: U4.16, U5.1

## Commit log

2018-02-05 inital commit
    [train_horn.kicad_pcb, train_horn.sch]
2018-02-08 not using internal comparitor for now, must solve problem of comparitor and timer not working together
2018-02-08 add audio amplifier to circuit rearange page layout remove comparitor references
    [train_horn.sch]
2018-02-10 comparator does not function correctly, using external circuitry
2018-02-11 initial final schematic
    [train_horn.sch]
2018-02-11 pin swaps, audio amp shutdown
2018-02-11 initial calculations, ugly spreadsheet
    [LiPo Low Battery Comparator Calculations.xlsx]
2018-02-11 schematic annotation
    [train_horn.sch]
2018-02-12 project specific footprints
2018-02-12 swap speaker pins 1 and 2 to aid pcb layout
    [train_horn.sch]
2018-02-12 start pcb layout
    [train_horn.kicad_pcb]
2018-02-13 setting large componet location. Change PCB size
    [train_horn.kicad_pcb, train_horn.sch]
2018-02-15 moving things around
    [train_horn.kicad_pcb]
2018-02-18 add smd tact switch footprint
2018-02-18 add manufacture suggested footprint
2018-02-18 fancy up footprint
2018-02-18 add silkscreen
2018-02-18 laying things out
    [train_horn.kicad_pcb, train_horn.sch]
2018-02-18 move play button to P1.3 for PCB layout reasons
2018-02-19 finising touches on silkscreen
    [train_horn.kicad_pcb, train_horn.sch]
2018-02-19 add 9mm x 6mm P logo
2018-02-19 moved silkscreen L in from front
2018-02-19 add 3d models to PCB
    [BH-18650-PC.step, C_0805_2012Metric.step, EVQP7L01P.step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]
2018-02-20 update schematic component description fields
    [train_horn.sch]
2018-02-20 generate BOM
    [BOM.xlsx]
2018-02-20 update LED ref to reflect ref on schematic
    [train_horn.kicad_pcb]
2018-02-20 not sure how these got here, dont need for kicad 3d viewer. Must have been from FreeCAD script.
2018-02-21 removed dimension callout to switch center
    [train_horn.kicad_pcb]
2018-02-21 plot gerber output for manufacture
    [train_horn-B.Cu.gbr, train_horn-B.Mask.gbr, train_horn-B.Paste.gbr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]
2018-02-21 save after gerber output
    [train_horn.kicad_pcb]
2018-02-23 add alternative tact switch footprint and 3D model
    [C-1825027-8.step]
2018-02-23 add TH tact switch in place of microSMD switch, retained SMD switch as option
    [train_horn.kicad_pcb]
2018-02-23 KiCAD StepUp FreeCAD PCB to step
    [train_horn.FCStd]
2018-02-23 replot gerber and drill files
    [train_horn-B.Cu.gbr, train_horn-B.Mask.gbr, train_horn-B.Paste.gbr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]
2018-02-25 initial commit, play while button is held
2018-02-25 update low note frequency to 256Hz change io to #defines and cleaned up comments
2018-02-25 on initial start there would be a pause between pushing the play button and sound generation setting an inital value for timer_b seems to fix this
2018-02-28 format data to table
    [BOM.xlsx]
2018-03-02 clean up component discriptions
    [train_horn.sch]
2018-03-02 R7 add note in discription not to populate
    [train_horn.sch]
2018-03-02 R10, R13, R17 update from super expensive 0.1% resistor to reasonable 1%
    For some reason I chose a super expensive 3.6K 0.1% resistor when all the others are 1%. No need for super presision.
    [train_horn.sch]
2018-03-02 update gain jumper fields
    [train_horn.sch]
2018-03-02 update BOM with corrected fields
    Removed TP from bom list
    [BOM.xlsx]
2018-03-02 implement software loop to prevent lockup
    if button is double tapped microcontoller may lock up. Added software loop after button is relased to prevent button from being pressed so quickly.
2018-03-05 circuit annotations
2018-03-06 fix manufacture name in descriptions
    R5 and R14 had links instead of names in the manufacture description fields
    [BOM.xlsx, train_horn.sch]
2018-03-06 MCP7383 missing fields filled
    MCP7383 info fields were not filled out, corrected with porper info
    [train_horn.sch]
2018-03-06 blue led description style same as all components
    style points +1
    [train_horn.sch]
2018-03-06 add detailed BOM cost and pricing
2018-03-06 better BOM replaces this
    [BOM.xlsx]
2018-03-07 printing formating
2018-03-07 include alternative play switch
2018-03-11 plot schematic to pdf
2020-06-07 find missing libs / remap to new kicad version
    [train_horn-2020-06-07-11-38-39.sch]
2020-06-07 generate iBOM
    [train_horn.kicad_pcb]

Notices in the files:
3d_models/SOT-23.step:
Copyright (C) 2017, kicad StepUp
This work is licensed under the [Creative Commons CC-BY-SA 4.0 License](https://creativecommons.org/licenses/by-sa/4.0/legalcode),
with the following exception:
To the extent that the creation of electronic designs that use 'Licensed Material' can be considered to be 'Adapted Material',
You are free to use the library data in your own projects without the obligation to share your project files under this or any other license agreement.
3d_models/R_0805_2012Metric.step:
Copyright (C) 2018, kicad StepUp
